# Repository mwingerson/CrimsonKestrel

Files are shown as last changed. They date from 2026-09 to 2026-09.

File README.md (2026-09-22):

### CrimsonKestrel: Open-Source Weather & Solar Edge Node (v1.15.4)
This repository contains the reference architecture for a solar-boosted, low-power environmental monitoring station built around the **ESP32-C6 RISC-V SoC**.

Rather than a fragile "maker-grade" loop sketch, this firmware utilizes a high-reliability **Single-Shot Boot Execution Pattern** paired with robust hardware and software safety nets designed to create an incredibly reliable, "set-it-and-forget-it" testing platform.

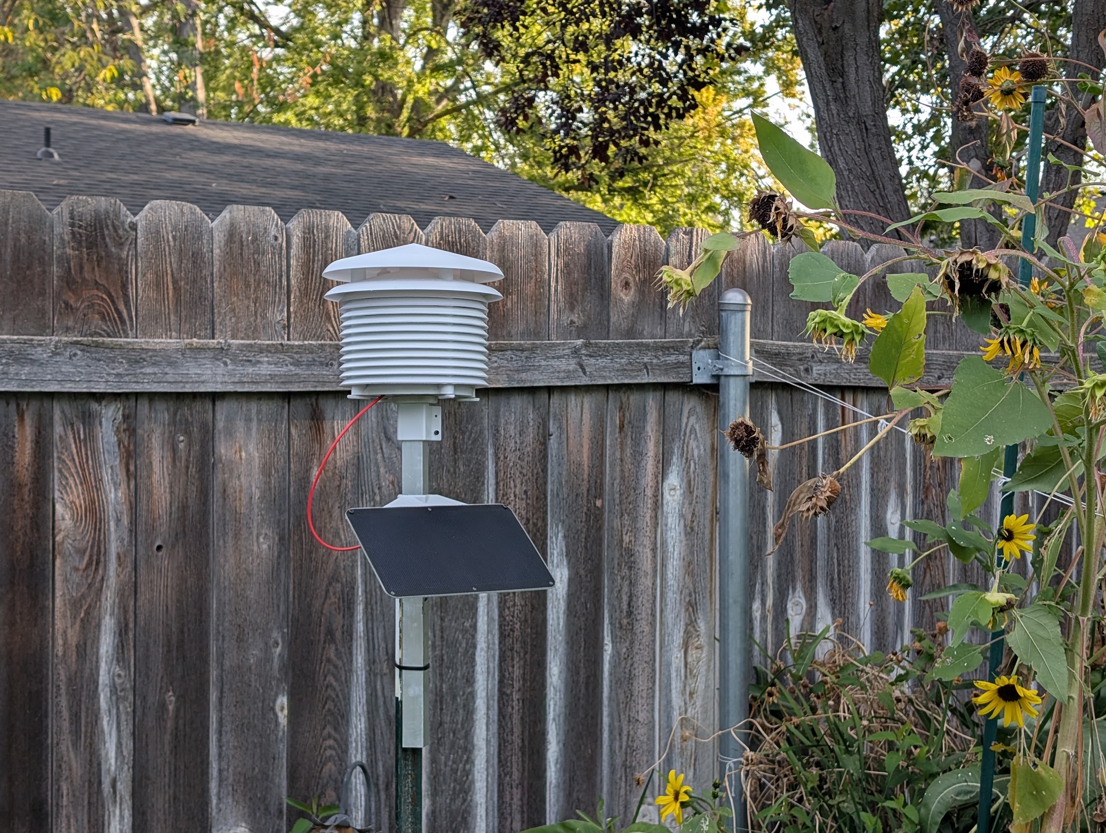
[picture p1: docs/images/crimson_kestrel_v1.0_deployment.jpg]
CrimsonKestrel v1.0 deployed in the backyard


---

#### 📑 Table of Contents
*   [System Architecture: The Hybrid Edge Pattern](#-system-architecture-the-hybrid-edge-pattern)
*   [Repository Directory Tree](#-repository-directory-tree)
*   [Getting Started](#-getting-started)
*   [Standalone Sourcing and Documentation Assets](#-standalone-sourcing-and-documentation-assets)

---

#### 🏗 System Architecture: The Hybrid Edge Pattern
To show quality design decisions while keeping the build highly accessible for makers, the system is architected as an overly robust, modular R&D platform. Instead of a single rigid design, this approach supports a wide range of interchangeable sensors for testing, availability, and budget. This allows anyone from any environment to build a simple, low-cost weather station using parts they already have or can easily afford, while separating physical environmental data collection from heavy data processing:

```
[ Outdoor ESP32-C6 Node ] 
       │ 
       │  (1. Single-Shot Boot: Sample -> Connect -> Decoupled JSON Payloads -> Deep Sleep)
       ▼ 
[ Indoor Gateway (Raspberry Pi @ <GATEWAY_IP>) ]
       │
       ├──► [ MQTT Broker (Mosquitto) ]
       ├──► [ Time-Series Database (InfluxDB) ]
       └──► [ Visualization Dashboard (Grafana) ]
```

*   **The Edge Node:** Wakes up from hardware deep sleep, takes rapid, averaged sensor samples, negotiates Wi-Fi/MQTT sockets, fires decoupled, nested JSON payloads, and drops back into deep sleep.
*   **The Gateway:** Lives indoors on permanent wall power. It handles heavy networking, data storage, third-party weather aggregator API pushing (such as Weather Underground, CWOP, or Home Assistant), and visualization dashboards.

---

#### 📂 Repository Directory Tree
A clean, decoupled directory structure immediately communicates professional maturity:
```
CrimsonKestrel-edge/
├── .gitignore                      <-- Publicly ignores secrets.h
├── LICENSE                         <-- MIT License
├── README.md                       <-- This document
├── BOM.md                          <-- Standalone Bill of Materials & Sourcing Guide
├── BRINGUP.md                      <-- Prototype Assembly & First-Time Bring-Up Guide
├── docs/
│   ├── SETUP.md                    <-- Arduino flashing config & gateway/Docker/Grafana walkthrough
│   ├── REFERENCE.md                <-- Firmware safeguards, LED codes, credentials pattern, JSON schemas
│   ├── images/
│   │   ├── crimson_kestrel_banner.png
│   │   ├── crimson_kestrel_logo.png
│   │   ├── prototype.jpg           <-- Real-world cardboard-mounted prototype photo
│   │   └── crimson_kestrel_v1.0_deployment.jpg <-- v1.0 node deployed in the field
│   ├── adr/
│   │   ├── adr-0001-hybrid-edge.md
│   │   ├── adr-0002-device-observability.md
│   │   ├── adr-0003-decoupled-schemas.md
│   │   └── adr-0004-framework-selection.md
│   └── postmortems/
│       └── mdns-underscore-bug.md  <-- OTA/mDNS underscore bootloop bug write-up
└── firmware/
    └── CrimsonKestrel/
        ├── CrimsonKestrel.ino      <-- Rebranded and updated v1.15.4 Arduino source code
        ├── secrets.h               <-- Private local Wi-Fi and MQTT credentials
        └── secrets.example.h       <-- Public configuration template
└── gateway/
    └── crimson_kestrel_daemon.py   <-- Paho-MQTT gateway subscriber & log rotator
```

---

#### 🚀 Getting Started
*   **Building the hardware:** [BOM.md](BOM.md) (parts/sourcing) and [BRINGUP.md](BRINGUP.md) (assembly and first flash).
*   **Flashing firmware & standing up the gateway stack:** [docs/SETUP.md](docs/SETUP.md).
*   **Firmware safeguards, LED codes, credentials pattern, and JSON telemetry schemas:** [docs/REFERENCE.md](docs/REFERENCE.md).
*   **Design rationale:** [docs/adr/](docs/adr/) — Architectural Decision Records covering the hybrid edge split, device observability, telemetry schemas, and framework selection.
*   **Post-mortems:** [docs/postmortems/mdns-underscore-bug.md](docs/postmortems/mdns-underscore-bug.md) — the mDNS underscore/OTA bootloop bug and its fix.

---

#### 🛠️ Standalone Sourcing and Documentation Assets
To keep the repository clean and avoid support overhead, we maintain detailed, standalone documents for hardware assembly and components:
*   **BOM.md**: Complete, itemized Bill of Materials with pricing, manufacturer part numbers, sourcing links, and direct-solder wiring maps.
*   **BRINGUP.md**: Prototype Assembly & First-Time Flashing Guide detailing physical breadboard layout, star grounding, sensor pull-ups, and step-by-step firmware installation.
*   **docs/SETUP.md**: Arduino IDE flashing configuration and the full gateway/Docker/Grafana setup walkthrough.
*   **docs/REFERENCE.md**: Firmware safeguards, WS2812 LED color codes, the credentials abstraction pattern, and the JSON telemetry schemas.
*   **gateway/crimson_kestrel_daemon.py**: Production-grade Python ingestion daemon that subscribes to raw MQTT streams, validates payload metrics, and commits structured outputs to rolling daily logs.
*   **docs/images/prototype.jpg**: High-resolution photo of our card-mounted rapid prototyping bench used to validate logic states and bus connections during development.
*   **docs/images/crimson_kestrel_v1.0_deployment.jpg**: Photo of the v1.0 node deployed in the field (backyard), shown near the top of this README.
*   **docs/adr/**: Formal Architectural Decision Records (ADRs) documenting core design decisions:
    *   **ADR-0001: The Hybrid Edge Architecture**: Moving heavy processing indoors to achieve a microamp sleep baseline outdoors.
    *   **ADR-0002: Hardware-Based Device Observability**: Opting for register-gated I2C power monitoring over power-bleeding resistive dividers.
    *   **ADR-0003: Decoupled Multi-Topic Telemetry Schemas**: Separating ambient environmental metrics from transient system diagnostics.
    *   **ADR-0004: Development Framework Selection**: Selecting the Arduino ESP32 Core over ESP-IDF or Zephyr RTOS for rapid prototyping and accessibility.
*   **docs/postmortems/**: Write-ups of notable field/integration bugs and their root causes:
    *   **mdns-underscore-bug.md**: The RFC 1035 hostname violation that caused an OTA-triggered crash-on-boot loop.

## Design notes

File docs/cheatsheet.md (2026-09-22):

# 🛠️ Crimson Kestrel: Technical Cheatsheet & Quick Reference

This cheatsheet compiles critical terminal commands, physical pinouts, electrical constraints, and container management instructions into a single rapid-lookup reference guide.

---

## 🔌 1. Hardware Pinout & Wiring Guides

### A. AM2302 / DHT22 Sensor
*   **Protocol:** Proprietary Single-Bus Serial (timing-based signaling, *not* standard 1-Wire).
*   **Logic Level:** Match supply voltage ($V_{CC}$). For $3.3	ext{V}$ microcontrollers (ESP32-C6 / ESP8266), power the sensor with **$3.3	ext{V}$** directly to ensure native $3.3	ext{V}$ logic levels.

#### Standalone 4-Pin Package
Looking directly at the front grid face with pins pointing downwards:
| Pin Number | Name | Connection Target | Purpose |
| :--- | :--- | :--- | :--- |
| **Pin 1 (Left)** | $V_{CC}$ | $3.3	ext{V}$ Bus Rail | Main supply voltage. |
| **Pin 2** | DATA | ESP32-C6 GPIO1 | Single-wire data line. **Requires a physical $4.7	ext{k}\Omega$ to $10	ext{k}\Omega$ pull-up resistor to $V_{CC}$.** |
| **Pin 3** | NC | *Floating* | Not Connected. |
| **Pin 4 (Right)** | GND | GND Bus Rail | Common star ground plane connection. |

*Note: If utilizing a pre-mounted 3-pin breakout module, the pull-up resistor is typically already integrated on the breakout PCB.*

---

### B. Ebyte ESPC6-WROOM-32 Pin Mapping Reference
High-density mapping of active testing pins utilized across the prototype:
| Module Pin | Pin Name | HW Function | Internal Role & Usage |
| :--- | :--- | :--- | :--- |
| **Pin 1** | GND | Ground | Connected to common star ground plane. |
| **Pin 2** | 3V3 | Power In | Rock-solid $3.0	ext{V}$ to $3.6	ext{V}$ supply. |
| **Pin 3** | EN | Chip Enable | Active HIGH (pulls up internally). Pull LOW to turn off. |
| **Pin 15** | IO9 | Boot Strap | **Strapping Pin:** Must be HIGH at reset for normal Flash Boot. Pull LOW at reset to force UART Download Mode. |
| **Pin 17** | IO19 | GPIO19 / SDA | Shared hardware I2C Data line. |
| **Pin 18** | IO20 | GPIO20 / SCL | Shared hardware I2C Clock line. |
| *(see module datasheet)* | IO1 | GPIO1 | DHT22 single-bus serial data input line (chosen to avoid strapping-pin conflicts). |
| **Pin 24** | RXD0 | U0RXD | USB/JTAG Virtual COM port RX (serial console debug). |
| **Pin 25** | TXD0 | U0TXD | USB/JTAG Virtual COM port TX (serial console debug). |

---

## 💻 2. Remote File Transfer & Networking (`scp`)

Always run these commands from your **local terminal** (not from inside an active SSH session):

### A. Push Files / Folders (Local to Gateway)
*   **Recursively Copy Enclosure STL Directory:**
    ```bash
    scp -r ./hardware/enclosure/ <GATEWAY_USER>@<GATEWAY_IP>:~/wrkspc/weather_station_staging/hardware/
    ```
*   **Push Single Configuration File:**
    ```bash
    scp ./docker-compose.yml <GATEWAY_USER>@<GATEWAY_IP>:~/wrkspc/weather_station_staging/
    ```

### B. Pull Files / Folders (Gateway to Local)
*   **Download Completed Telemetry CSV Logs:**
    ```bash
    scp -r <GATEWAY_USER>@<GATEWAY_IP>:~/wrkspc/weather_station_staging/data/ ~/Downloads/
    ```
*   **Pull Single Gateway Daemon Script:**
    ```bash
    scp <GATEWAY_USER>@<GATEWAY_IP>:~/wrkspc/weather_station_staging/gateway/crimson_kestrel_daemon.py ~/Downloads/
    ```

### C. SSH Command-Line Escape Sequence (Transfer on the Fly)
If you are already in an active SSH session and want to issue an inline recursive transfer back to your local computer without opening a new tab:
1. Hit `Enter`.
2. Type **`~C`** (Tilde followed by capital C). The prompt will change to `ssh>`.
3. Issue the local execution escape:
   ```text
   ssh> ! scp -r <GATEWAY_USER>@<GATEWAY_IP>:/home/<GATEWAY_USER>/wrkspc/weather_station_staging/ ~/Downloads/
   ```
4. Hit `Enter` to return seamlessly to your active remote shell.

---

## 🤖 3. Docker & Stack Observability Reference

### A. Quick Diagnostics & Status
*   **List Running Containers & Exposed Ports:**
    ```bash
    docker ps
    ```
*   **Show All Containers (Including Stopped/Crashed Services):**
    ```bash
    docker ps -a
    ```
*   **Tail Live Processing Logs (Last 50 Lines):**
    ```bash
    docker logs crimson_daemon --tail 50
    docker logs crimson_mosquitto --tail 50
    docker logs crimson_influxdb --tail 50
    ```

### B. Host & Stack Permission Maintenance
*   **Resolve Docker API "Permission Denied" Errors (Add User to Group):**
    ```bash
    sudo usermod -aG docker $USER
    newgrp docker
    ```
*   **Resolve Grafana "Permission Denied" Directory Write Loops:**
    ```bash
    sudo chown -R 472:472 ./grafana/data
    ```

### C. Resetting and Wiping Stack Cache (The Data Wipe Options)
*   **Nuclear Option: Purge Entire Host Docker Cash (All Containers, Volumes, & Networks):**
    ```bash
    docker system prune -a --volumes -f
    ```
*   **Reset Weather Station Stack Only (Clear Persistent Data Volumes):**
    ```bash
    docker compose down -v
    docker compose up -d
    ```

---

## 📡 4. MQTT Broker & Ingestion Diagnostics

### A. Monitoring Live Subnet Traffic (MQTT Sniffing)
*   **Listen to All Subscribed Topics (Great for confirming packet ingress):**
    ```bash
    docker exec -it crimson_mosquitto mosquitto_sub -h localhost -p 1883 -t "#" -v
    ```
*   **Subscribe Specifically to Aligned Environmental Topics:**
    ```bash
    docker exec -it crimson_mosquitto mosquitto_sub -h localhost -p 1883 -t "telemetry/+/weather" -v
    ```

### B. Simulating Telemetry Ingress (Manual Publishing)
*   **Post Environmental Payload to Broker:**
    ```bash
    docker exec -it crimson_mosquitto mosquitto_pub -h localhost -p 1883 -t "telemetry/weather_node_01/weather" -m '{"client_id":"weather_node_01","environment":{"temperature_c":22.3,"humidity_pct":38.5}}'
    ```
*   **Post Power & Diagnostics Payload to Broker:**
    ```bash
    docker exec -it crimson_mosquitto mosquitto_pub -h localhost -p 1883 -t "telemetry/weather_node_01/system" -m '{"client_id":"weather_node_01","system":{"version":"1.15.4","uptime_ms":3585},"power":{"bus_voltage_v":3.82,"load_current_ma":36.9,"shunt_voltage_mv":3.69}}'
    ```

---

## 📦 5. Firmware Build & Erase Tools (CLI Flash Option)

If pushing firmware directly over USB or utilizing emergency recovery CLI tools rather than the Arduino IDE:

### A. Arduino CLI Library Ingress
*   **Install Required Library Dependencies:**
    ```bash
    arduino-cli lib install "PubSubClient"
    ```

### B. Direct Python-Based Over-The-Air (OTA) Flash
If local mDNS network resolution fails in the Arduino IDE port selector list, push the compiled application binary directly via IP:
```bash
python3 ~/.arduino15/packages/esp32/hardware/esp32/3.0.0/tools/espota.py -i <NODE_IP> -p 8266 -a <OTA_PASSWORD> -f /tmp/arduino/build/CrimsonKestrel.ino.bin
```

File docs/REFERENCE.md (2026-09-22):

# Reference: Firmware Safeguards, LED Codes, Credentials Pattern & Telemetry Schemas

Lookup material for the firmware's internals — safety nets, status LED meanings, the credentials
pattern, and the JSON payloads it publishes. For flashing/gateway setup steps, see
[SETUP.md](SETUP.md).

---

#### 🛡 Core Firmware Safeguards (The "Bulletproofing")
Let's be honest: nobody wants to drag a 20-foot ladder out to their roof in the middle of a freezing downpour just to press a tiny physical reset button because the Wi-Fi hiccuped or an I2C sensor locked up. To prevent those unnecessary roof-climbing adventures and keep your station running 24/7, the firmware includes several robust, built-in safety nets:

##### 1. Hardware Watchdog Timer (WDT)
If an I2C transaction hangs due to electrical noise, or a Wi-Fi handshake locks up, the hardware watchdog automatically triggers a full system reset.
*   **Implementation:** The ESP32-C6's internal Main System Watchdog Timer (MWDT) is initialized at boot with a **15-second timeout**. The watchdog is fed continuously through the execution path; if any task hangs, the hardware reboots the processor to recover.

##### 2. Connection-Timeout & Graceful Fallbacks
A major failure mode in field deployments is a node getting stuck trying to connect to an offline router, draining its battery in minutes.
*   **Implementation:** The Wi-Fi connection loop uses a non-blocking timeout. If connection is not established within **10 seconds**, the code gracefully halts, aborts transmission, configures low-power states, and goes to sleep.

##### 3. Data Sanitization & Range Validation
Physical sensors can report NaN (Not a Number) or severe spikes during startup transients or low-voltage states.
*   **Implementation:** Outlier range validation is run on all telemetry before packaging:
    *   **DHT22:** Rejects relative humidity readings outside 0.0 to 100.0 and NaN states.
    *   **INA219:** Rejects bus voltage readings outside 0.0 V to 26.0 V (max chip limit) or NaN states.
    *   If a reading is invalid, the node logs the error, flags the payload as invalid, and bypasses transmission to protect database hygiene.

##### 4. Cloud-Driven Debug Sleep Override State
During active workspace debugging, waiting 5 minutes between iterations slows down development. The node supports dynamic state shifting:
*   On boot, the node subscribes to a command topic. If it reads a retained "ON" debug command, it overwrites its standard 5-minute deep sleep timer with a rapid **5-second cycle** and pulses its RGB LED to signal active debug mode. This allows you to observe full boot-up sequences, Wi-Fi negotiations, and sleep routines rapidly at your desk.

---

#### 🚦 Diagnostic Device Observability (WS2812 LED)
##### 🎨 WS2812 Visual Status LED Color Codes
To assist in local debugging and bring-up without having a serial monitor attached, the onboard WS2812 LED flashes standard, high-density color-coded states. Because these color codes are documented directly using GitHub-compatible hex swatches, they will render as beautifully colored visual dots directly on your GitHub landing page:

| LED State | Visual Swatch | Hex Code | R, G, B | System State & Meaning |
| --- | --- | --- | --- | --- |
| **Solid Orange** | 🟧 #964B00 | #964B00 | 150, 75, 0 | **System Booting:** Microcontroller powering up, establishing internal clock registers, and configuring hardware peripherals. |
| **Pulsing Yellow** | 🟨 #964B00 | #964B00 | 150, 75, 0 (pulse) | **Wi-Fi Negotiating:** Active, non-blocking connection attempt to your local Wi-Fi gateway router. |
| **Flash Green** | 🟩 #009600 | #009600 | 0, 150, 0 | **Publish Successful:** Environmental and system power telemetry successfully packaged and published to your MQTT broker. |
| **Solid Purple** | 🟪 #640064 | #640064 | 100, 0, 100 | **Maintenance Window:** Active 2-second idle window listening on command topics for OTA override packages. |
| **Pulsing Cyan** | ⬜ #009696 | #009696 | Variable | **Debug Loop Active:** Dynamic MQTT debug mode triggered; deep sleep is overridden to a rapid 5-second sampling loop. |
| **Solid Blue** | 🟦 #000096 | #000096 | 0, 0, 150 | **OTA Mode Engaged:** Maintenance Mode active; the web-server is open and awaiting wireless firmware binaries. |
| **Pulsing Blue** | 🟦 #000096 | #000096 | 0, 0, pulse | **Active OTA Download:** High-speed wireless download of new compiled .bin firmware packets. |
| **Solid Cyan** | ⬜ #009696 | #009696 | 0, 150, 150 | **Flash Write:** Actively committing new firmware blocks to local partition slots. |
| **Solid Green** | 🟩 #00FF00 | #00FF00 | 0, 255, 0 | **Flash Success:** Firmware update completely written and verified; system is rebooting into the new software layer. |
| **Solid Red** | 🟥 #960000 | #960000 | 150, 0, 0 | **System Error:** Hardware initialization failure (DHT22 missing, INA219 offline), or data sanitization outlier rejected. |
| **Fast Red Flash** | 🟥 #960000 | #960000 | 150, 0, 0 (fast) | **Network Timeout:** Wi-Fi connection timed out or MQTT broker unreachable. Pipeline gracefully aborted to protect battery. |

---

#### 🔒 Safe Credentials Abstraction Pattern
To keep your private home router credentials and server IP addresses completely safe from leakages on public repositories, **CrimsonKestrel** uses a professional **Safe Include Pattern**.
Inside the main firmware sketch, the C++ preprocessor dynamically checks for the presence of a local, untracked secrets.h file:

```cpp
#if __has_include("secrets.h")
  #include "secrets.h"         // Pulls actual credentials locally
#else
  #include "secrets.example.h" // Fallback template so repo compiles out-of-the-box
#endif
```

By adding `secrets.h` and `*secrets.h` to your `.gitignore` file, your private information remains strictly on your local PC (`DIBShip`) while others can easily clone the repo and compile it using the provided `secrets.example.h` blueprint!

---

#### 📊 Decoupled JSON Telemetry Schemas (v1.15.4)
To maintain a clean database structure and separate transient environmental states from system diagnostics, the node publishes two distinct JSON payloads during its single-shot boot routine:

##### 1. Ambient Weather Telemetry
Pushed directly to your database parser to record ambient environmental updates:
**Topic:** `telemetry/weather_node_01/weather`
```json
{
  "client_id": "weather_node_01",
  "environment": {
    "temperature_c": 19.6,
    "humidity_pct": 38.7
  }
}
```

##### 2. Device System & Power Observability
Pushed to your system health logger to track battery charge levels and hardware status:
**Topic:** `telemetry/weather_node_01/system`
```json
{
  "client_id": "weather_node_01",
  "system": {
    "version": "1.15.3",
    "uptime_ms": 3594
  },
  "power": {
    "bus_voltage_v": 3.93,
    "load_current_ma": 30.4,
    "shunt_voltage_mv": 3.04
  }
}
```

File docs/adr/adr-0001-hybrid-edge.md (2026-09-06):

# ADR-0001: Hybrid Edge Architecture

## Status
Approved

## Context
To build a reliable solar-powered weather station, we evaluated two primary architectural patterns for the core processing system:

1. **Outdoor Single-Board Computer (SBC):** Deploying a Linux-based SBC (such as a Raspberry Pi) directly in the outdoor weather station enclosure [cite: 427]. This offers extreme ease of development, high-level programming language support (Python pipelines), and native database/broker execution at the physical edge [cite: 428].
2. **Hybrid Edge Architecture:** Splitting processing and environmental sampling between an ultra-low-power outdoor microcontroller (MCU) edge node and a permanently powered indoor Linux gateway [cite: 429, 436].

### Power & Cost Engineering Analysis
A standard Linux-based SBC (e.g., Raspberry Pi 4) lacks a native hardware-level deep sleep state and draws a continuous active load of roughly 3 Watts (~600mA @ 5V) [cite: 428, 430]. Under extreme off-grid conditions (designing for 4 days of solar blackout/autonomy at mid-latitudes), the energy requirements scale exponentially [cite: 431]:

* **Daily Energy Draw:** 3W * 24h = 72 Watt-hours (Wh) per day [cite: 430].
* **4-Day Autonomy Target:** 72 Wh/day * 4 days = 288 Wh [cite: 431].
* **Battery Sizing (12V nominal LiFePO4):** 288 Wh / 12V = 24 Amp-hours (Ah) [cite: 431].
* **Solar Panel Sizing (4 winter peak sun hours):** 100 Wh target / 4 hours = 25 Watts minimum [cite: 432]. Applying a standard 1.5x to 2x safety factor requires a **50W to 100W monocrystalline solar panel** [cite: 432].

This outdoor SBC approach demands a heavy, expensive system [cite: 431, 435]: a motorcycle-sized 12V LiFePO4 battery [cite: 431], a massive solar panel [cite: 432], a commercial MPPT charge controller [cite: 433], an industrial DC-DC buck converter [cite: 433], and a dedicated low-power hardware supervisor to trigger clean shutdowns to prevent SD card corruption [cite: 433]. This heavily violates our core constraint of building an accessible, highly replicable, and low-cost R&D station [cite: 413, 435].

Conversely, an optimized microcontroller edge node can utilize a **Single-Shot Boot Execution Pattern** [cite: 235, 413]: waking up from hardware deep sleep, taking rapid averaged sensor samples, negotiating Wi-Fi/MQTT sockets, transmitting a lightweight telemetry packet, and immediately returning to deep sleep [cite: 235]. An MCU like the ESP32-C6 has a deep-sleep current draw of approximately 15–30 µA [cite: 235], allowing the entire outdoor setup to run continuously on a single 18650 Lithium-Ion cell and a compact, lightweight 5V solar panel [cite: 235, 435].

## Decision
We reject the outdoor Single-Board Computer design and officially adopt the **Hybrid Edge Architecture** [cite: 429, 436]:

1. **Outdoor Edge Node:** Standardize on an ultra-low-power ESP32-C6 microcontroller node running a non-blocking single-shot boot pattern [cite: 235, 413]. It is powered by a small 5V solar panel and a single 18650 battery cell [cite: 235, 435].
2. **Indoor Gateway:** Deploy a Linux-based gateway (such as a Raspberry Pi) **indoors on permanent wall power** [cite: 429, 436]. This gateway hosts the local MQTT broker (Mosquitto), a time-series database (InfluxDB), and a visualization platform (Grafana) [cite: 429, 436]. The gateway is responsible for subscribing to the node's telemetry, handling data storage, running calibration algorithms, and pushing data to third-party aggregators (such as Weather Underground, CWOP, or Home Assistant) [cite: 423, 429].

## Consequences

### Consequences (Pros)
* **Drastic SWaP-C Reduction:** Eliminates the need for bulky 12V marine/motorcycle batteries [cite: 431] and large 50W+ solar panels [cite: 432]. The system can be safely assembled and deployed on a standard 3D-printed mounting arm using affordable, widely available maker hardware [cite: 235, 435].
* **System Durability:** Minimizes outdoor failure points. Eliminates mechanical wear, moving parts, and complex off-grid power-switching regulators in the weather enclosure [cite: 433, 477].
* **No SD Card Corruption Risk:** The outdoor node operates completely stateless out of raw flash memory, while the database runs on a safe, indoor, line-powered system [cite: 429, 433].
* **Clean Separation of Concerns:** The outdoor node remains purely an environmental telemetry transducer [cite: 235], while the gateway handles heavy networking, processing, and visualization tasks [cite: 429].

### Consequences (Cons)
* **Local Subnet Requirement:** The outdoor node must remain within wireless range of the indoor gateway's local network (Wi-Fi 6 or mDNS range) [cite: 27, 429].
* **Gateway Dependency:** Environmental data cannot be visualized or aggregated if the indoor gateway is powered off or disconnected from the local network.

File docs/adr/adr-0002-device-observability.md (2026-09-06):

# ADR-0002: Hardware-Based Device Observability

## Status
Accepted

## Context
Deploying an outdoor, solar-boosted telemetry node requires real-time monitoring of battery state-of-charge (SoC) and system current draw to predict run-time limits and detect hardware anomalies. 

We evaluated two primary power-sensing methods:
1. **Resistive Voltage Divider (Analog ADC Pin):** A standard two-resistor network stepping down battery voltage to fit within the microcontroller's ADC limits.
2. **Dedicated I2C Power Monitor (INA219 / INA226):** An external integrated circuit measuring both bus voltage and differential voltage drop across a low-resistance inline shunt.

### Trade-Off Analysis

| Criteria | Resistive Voltage Divider (ADC) | Dedicated I2C Power Monitor (INA219) |
| :--- | :--- | :--- |
| **Metrics Captured** | Voltage only (non-linear battery estimation) | Voltage, Shunt Voltage, Current (mA), and calculated Power (mW) |
| **Parasitic Current** | Constant leakage to ground (mitigated only via complex high-side MOSFET gating) | Native, register-driven software shutdown modes reducing current draw to < 15 µA |
| **Noise Immunity** | Highly susceptible to RF transients during active Wi-Fi transmission bursts | Isolated digital I2C telemetry with internal averaging and high-frequency filtering |
| **Component Count** | 2 resistors, 1 P-channel MOSFET, 1 NPN transistor, biasing passives | 1 integrated circuit breakout, decoupling capacitor |
| **PCB Footprint** | Large discrete footprint, complex trace routing | Small, modular footprint sharing the existing digital I2C bus |

## Decision
We decided to standardize on the **INA219 high-side I2C current and power monitor** for hardware-based device observability. 

The sensor will be placed upstream of the main voltage regulation and distribution rails (high-side sensing) to ensure an unbroken ground plane across the microcontroller and other peripherals, preventing ground loop offsets.

## Consequences
* **Precision Telemetry:** We gain real-time, microamp-resolution insights into the active transmission spikes and deep-sleep baselines of the microcontroller.
* **Firmware Complexity:** We must initialize and configure the INA219 via standard I2C wire transactions at boot.
* **Zero Parasitic Bleed:** Prior to triggering the microcontroller's deep sleep state, the firmware must write to the INA219 Configuration Register to put the IC into I2C power-down mode (~15 µA draw).
* **Shared Bus Architecture:** The INA219 shares physical I2C pins with any future expansion sensors, eliminating GPIO pin-budget bottlenecks.

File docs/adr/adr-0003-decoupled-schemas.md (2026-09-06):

# ADR-0003: Decoupled Multi-Topic Telemetry Schemas

## Status
Accepted

## Context
In early prototyping phases, environmental weather stations typically bundle all sensor outputs (temperature, humidity, battery voltage, up-time, etc.) into a single, monolithic JSON payload published to a single MQTT topic.

While simple to write, this monolithic approach presents severe architectural drawbacks for production-scale deployments:
* **Database Hygiene:** Systems tracking ambient environmental metrics (e.g., InfluxDB) are forced to continuously ingest and store static system metadata (such as firmware version and boot up-time).
* **Payload Bloat:** Network bandwidth is wasted sending slow-changing system diagnostics at the same frequency as rapid environmental changes.
* **Automation Coupling:** Home automation systems (like Home Assistant) must run complex parsing scripts on a single payload to extract independent entities.

## Decision
We decided to **decouple the telemetry payloads** into two distinct, structured JSON schemas published to independent MQTT topics:

1. **Environmental Weather Telemetry (`telemetry/<CLIENT_ID>/weather`):**
   Contains strictly ambient environmental metrics.
   ```json
   {
     "client_id": "<CLIENT_ID>",
     "environment": {
       "temperature_c": 19.6,
       "humidity_pct": 38.7
     }
   }
   ```

2. **System & Power Observability (`telemetry/<CLIENT_ID>/system`):**
   Contains system metadata, diagnostic metrics, and battery health telemetry.
   ```json
   {
     "client_id": "<CLIENT_ID>",
     "system": {
       "version": "1.15.2",
       "uptime_ms": 3594
     },
     "power": {
       "bus_voltage_v": 3.93,
       "load_current_ma": 30.4,
       "shunt_voltage_mv": 3.04
     }
   }
   ```

## Consequences
* **Decoupled Data Ingestion:** Database parsers and time-series databases can subscribe strictly to the `/weather` topic, preserving database hygiene.
* **Payload Efficiency:** System diagnostic payloads can eventually be duty-cycled at a lower rate than environmental payloads to conserve battery power.
* **Cleaner Home Automation:** Home Assistant can consume the two topics independently, mapping entities directly to their logical controls and graphs without heavy JSON post-processing.

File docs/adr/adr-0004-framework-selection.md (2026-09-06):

# ADR-0004: Development Framework Selection

## Status
Accepted

## Context
We evaluated the optimal software platform and development framework for writing high-reliability, low-power edge firmware on the ESP32-C6 RISC-V microcontroller.

Three primary options were considered:
1. **Espressif IoT Development Framework (ESP-IDF):** The native, bare-metal C-based SDK provided by Espressif.
2. **Zephyr RTOS:** A modular, secure, open-source real-time operating system optimized for resource-constrained resource devices.
3. **Arduino ESP32 Core (v3.0.0+):** A highly accessible C++ framework built on top of FreeRTOS tasks and the underlying ESP-IDF port.

### Trade-Off Analysis

| Criteria | Native ESP-IDF | Zephyr RTOS | Arduino ESP32 Core |
| :--- | :--- | :--- | :--- |
| **Low-Power Control** | Absolute, registers-level deep-sleep configurations | Excellent, native power-management subsystem | Fully accessible (wraps native ESP-IDF system APIs) |
| **Development Velocity** | Slow (verbose APIs, steep learning curve) | Slow (complex device-tree configurations, tooling setup) | **Extremely Fast** (large library ecosystem, clean syntax) |
| **Portability** | Locked to Espressif silicon | Excellent cross-architecture abstraction | Portable across major Maker/Hobbyist hardware |
| **Library Availability** | Moderate (requires porting custom drivers) | Low (requires custom Zephyr-compliant device-tree drivers) | **Excellent** (thousands of community-maintained drivers) |
| **Watchdog & OTA** | Robust, requires custom partition logic | Native, robust | **Native & Simplified** (uses mDNS, ArduinoOTA, and WDT libraries) |

## Decision
We decided to standardize on the **Arduino ESP32 Core (v3.0.0+)** running on top of underlying **FreeRTOS** APIs.

While Zephyr RTOS and native ESP-IDF are outstanding for enterprise-only products, the Arduino ESP32 Core offers the perfect balance of development velocity and hardware accessibility for a robust, open-source research and development platform. It allows us to utilize the extensive Arduino library ecosystem for sensor bring-up while still leaving low-level ESP-IDF system APIs (like deep-sleep and watchdog timers) fully accessible.

## Consequences
* **Rapid Prototyping:** We can easily swap out complex sensors (such as moving from a basic DHT22 to a Sensirion SPS30 or AS3935 lightning sensor) using verified, pre-existing libraries.
* **Production-Grade Safety:** We still maintain enterprise-level safety nets (including the 15-second Main System Watchdog and OTA rollback partitions) by calling direct low-level ESP-IDF functions when required.
* **Accessibility:** Other developers can easily clone, audit, and compile the firmware in their local environments without needing to configure complex command-line toolchains or device-trees.

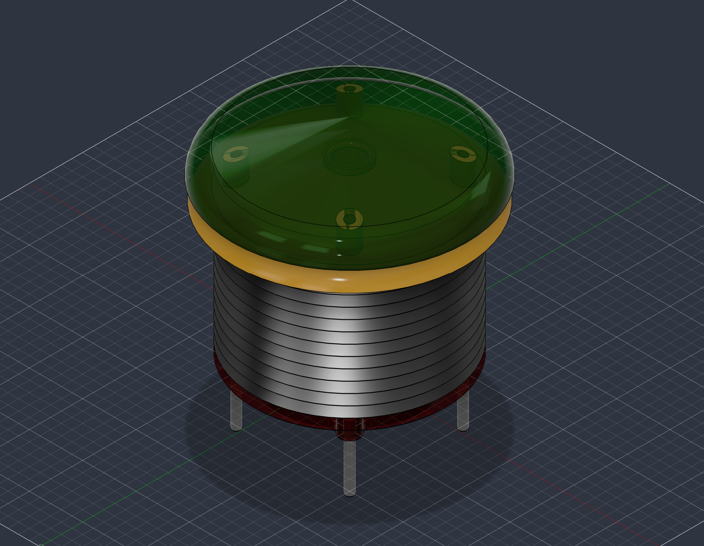
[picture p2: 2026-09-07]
docs/images/enclosure_3D_model_v0.5.png

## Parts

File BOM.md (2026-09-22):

# Bill of Materials (BOM) — CrimsonKestrel

This document serves as the official, production-grade Bill of Materials (BOM) and Sourcing Guide for **CrimsonKestrel**, a highly optimized, solar-powered edge telemetry node built around the ESP32-C6 RISC-V SoC. 

This reference architecture serves as an overly robust, low-power R&D platform designed to be highly accessible and affordable for hobbyists. By utilizing a single 18650 Lithium-Ion cell, a small solar panel, and modular breakout boards, anyone can build a reliable 24/7 weather station using the parts they have available or can afford, while maintaining an ultra-low sleep current baseline (~15–30 µA).

---

## 📊 Phase 1: MVP Core Bill of Materials

These components form the baseline telemetry node designed in Phase 1. All connections are designed for standard **2.54mm (0.1") pitch male/female headers** or direct-solder prototyping boards.

| Ref | Component Name | Manufacturer / MPN | Key Technical Specifications | Qty | Est. Cost (USD) | Primary Sourcing | Design & Integration Notes |
| :--- | :--- | :--- | :--- | :--- | :--- | :--- | :--- |
| **U1** | **ESP32-C6 Dev Board** | Meshnology / [QS-ESP32 C6 N16](https://www.amazon.com/dp/B0FKH69BP7) | Core board with 16MB Flash, RISC-V Single-Core CPU, 2.4GHz Wi-Fi 6, BLE 5, Zigbee 3.0, and Thread. Compatible with ESP32-WROOM series boards, Type-C connector. | 1 | $4.50 – $6.00 | [Amazon](https://www.amazon.com/dp/B0FKH69BP7) | Provides the core processing, network socket negotiation, and deep sleep routines. Features USB CDC for direct debug monitoring over Type-C. |
| **U2** | **INA219 Power Monitor Breakout** | Texas Instruments / INA219AIDR (Adafruit PID 904 or Generic) | I2C high-side current and voltage monitor, ±26V common-mode input range, 12-bit ADC, onboard 0.1Ω 1% shunt resistor. | 1 | $2.00 – $4.50 | Mouser, Adafruit, Amazon | Monitors battery health and real-time current draw. Breakout includes physical 10kΩ pull-up resistors on SDA/SCL lines. |
| **SEN1** | **DHT22 Humidity & Temp Sensor** | Aosong / AM2302 | Ambient temperature range: -40°C to 80°C (±0.5°C), relative humidity: 0–100% (±2–5% RH). Single-bus serial protocol. | 1 | $3.00 – $4.00 | Adafruit, SparkFun, Amazon | Measures primary environmental metrics. Can use standard 3-pin PCB module with pre-installed pull-up, or bare 4-pin sensor with external resistor. |
| **D1** | **WS2812 RGB LED** | Worldsemi / WS2812B (Onboard GPIO8) | Addressable RGB LED, single-wire control protocol. Integrated directly on Dev Board. | 1 | Included | Built-in on Node Board | Configured in firmware as a multi-state visual indicator for booting, network socket errors, active debug mode, and OTA progress. |
| **BAT1** | **18650 Li-Ion Cell** | Samsung / INR18650-30Q or Panasonic / NCR18650B | 3.7V Nominal, 3000mAh capacity, chemistry optimized for high reliability and steady discharge. | 1 | $5.00 – $7.00 | 18650BatteryStore, LiionWholesale | Main system power reservoir. Size is highly optimized for multi-week operation even under extended solar blackout. |
| **U3** | **Solar Charger & Board** | WatangTech / [5V Solar Charge Controller](https://www.amazon.com/dp/B0FQP915R9) | JEITA Li-ion Battery Charger with dual USB output, 5V and 3.3V power rails, and built-in 18650 battery holder. Compatible with Arduino, RPi, STM32. | 1 | $5.00 – $7.00 | [Amazon](https://www.amazon.com/dp/B0FQP915R9) | Automatically manages solar charging cycles for the 18650 cell, and exposes highly convenient 5V and 3.3V supply lines. |
| **PV1** | **Monocrystalline Solar Panel** | Voltaic Systems / [5.5 Watt 6 Volt Panel](https://www.amazon.com/dp/B085W9KG6V) | 5.5 Watt, 6 Volt high-performance monocrystalline cells. Waterproof, UV-resistant, scratch-resistant ETFE laminate casing. | 1 | $35.00 – $40.00 | [Amazon](https://www.amazon.com/dp/B085W9KG6V) | High-durability charging source designed to gather generous power even under partial shade or low daylight winter months. |
| **R1** | **DHT22 Pull-Up Resistor** | Generic / Metal Film 1/4W | 4.7kΩ to 10kΩ resistor, 1% tolerance. | 1 | $0.10 | Mouser, DigiKey, Parts Bin | Placed between VCC and DATA pins of bare 4-pin DHT22 to keep single-bus line from floating. Skip if using 3-pin breakout board. |

---

### 🚦 The WS2812 "Device Observability" Pivot
A common question when designing low-power remote nodes is: *Why spend precious power on an addressable WS2812 RGB LED (which can draw up to 50mA when fully bright) instead of a simple single-color indicator LED or no LED at all?*

The decision is driven by **strict engineering trade-offs** and **field survivability**:
1. **Single-Pin Multi-State Diagnostics:** A traditional single-color status LED only offers two states (On or Off). To represent the multiple critical stages of our single-shot boot pipeline (Booting -> Sensor Init -> Wi-Fi Connect -> MQTT Handshake -> Payload Validation -> Active Listening -> Sleep), we would need a bank of 5+ separate LEDs, which would hijack precious GPIO pins, increase BOM costs, and clutter the physical board. The WS2812 uses **exactly one physical GPIO pin (GPIO8)** to output a high-density, multi-color diagnostic spectrum.
2. **Zero-Power Deep Sleep Isolation:** The WS2812 is only powered and active during the brief **2-to-3 second active boot and transmission window**. The instant the transmission completes and the node prepares to sleep, the firmware executes `statusLED.clear()` and disables the LED completely. During deep sleep, the LED's power draw is non-existent, making its net daily energy consumption negligible (under 0.05% of our daily battery capacity).
3. **The "No-Ladder" Diagnostics Rule:** Let's be honest: nobody wants to drag a 20-foot ladder out to their roof in a freezing downpour just to attach a physical USB serial debugging cable because the station stopped updating. Having a high-density RGB status indicator allows you to perform a simple "ground-level binocular test" or check it from a window. If the node is struggling with your router, it pulses yellow; if the sensor is disconnected, it glows solid red; if it is ready for a firmware update, it turns solid blue.

## 🔌 Core Solder-Direct Master Wiring Map (PTH Spacing)

By designing for direct pin-to-pin soldering using standard **2.54mm (0.1") pitch pin headers**, we eliminate expensive proprietary connectors, lowering BOM costs and simplifying assembly.

All breakout modules share the physical I2C bus lines in parallel:

| Breakout Board Pin | ESP32-C6 Pin | Function | Electrical / Configuration Notes |
| :--- | :--- | :--- | :--- |
| **VCC / VIN (All)** | **3.3V** | Power Rail | Main system power (Common 3.3V supply). |
| **GND (All)** | **GND** | Ground Plane | Star ground configuration to prevent loops and signal noise. |
| **SDA (INA219)** | **GPIO19** | I2C Data | Communicates battery diagnostics. Shared hardware I2C bus. |
| **SCL (INA219)** | **GPIO20** | I2C Clock | Shared hardware I2C bus lines. |
| **DATA (DHT22)** | **GPIO1** | Single-Bus Serial | Uses an internal or external 10kΩ pull-up resistor to 3.3V. Chosen to avoid ESP32-C6 strapping-pin conflicts. |

---

## 💡 Sourcing & Assembly Best Practices

To ensure "right-first-time" assembly and protect against field failures, follow these professional prototyping rules:

### 1. The I2C Pull-Up "BOM Hack"
Standard I2C buses require physical pull-up resistors (typically $2\text{k}\Omega$ to $5\text{k}\Omega$) on SCL and SDA to ensure reliable high-speed communication. Relying strictly on the ESP32-C6's internal weak software pull-ups (typically $45\text{k}\Omega$) causes signal degradation and eventual system hangs.
*   **The Hack:** Standard off-the-shelf INA219 breakout modules already feature physical $10\text{k}\Omega$ pull-up resistors pre-soldered on-board. Wiring the breakout module directly to the I2C lines provides the necessary physical pull-up network for the entire bus, eliminating the need to solder discrete resistors on your proto-board.

### 2. Ground Plane Integrity & Star Grounding
High-speed wireless transmissions (ESP32-C6 Wi-Fi 6 active bursts up to 350mA) introduce significant electrical noise into physical power rails.
*   **Best Practice:** Implement a strict **Star Ground Configuration** where the ground pins from the ESP32-C6, INA219, and DHT22 are soldered to a single physical point on your perfboard. This prevents ground loops and stabilizes readings.
*   **Decoupling:** Place a $0.1\mu\text{F}$ ceramic capacitor close to the power pins of each peripheral to filter high-frequency switching noise.

---

## 🛣️ Phase 2: Extensible Platform Sourcing Guide

Because your battery capacity is large (3000mAh) and the ESP32-C6's single-shot sleep routine draws minimal power, you have abundant energy reserves. This allows you to scale up the weather station dynamically in Phase 2 by plugging these professional modules straight into your physical I2C bus and GPIO lines:

### 1. Wind Speed: Hobbyist Cup Anemometer
*   **Estimated Cost:** ~$15.00 – $25.00 (Standard replacement cup assemblies).
*   **Interface:** Digital GPIO Pin (Magnetic reed switch output).
*   **Integration:** Connect to **GPIO3**. Configured in firmware using the ESP32-C6's hardware **Pulse Count Controller (PCNT)** peripheral to count wind speed pulses in the background without stealing CPU cycles.

### 2. Storm Tracking: AS3935 Franklin Lightning Sensor
*   **Estimated Cost:** ~$22.00 – $35.00 (DFRobot Gravity or SparkFun Qwiic breakouts).
*   **Interface:** I2C (shares GPIO19/SDA and GPIO20/SCL) + 1 Hardware Interrupt Pin.
*   **Integration:** Connect the interrupt line to **GPIO2**. It will automatically wake the ESP32-C6 from deep sleep when electromagnetic storm pulses are detected up to 40 km away.

### 3. Air Quality: Sensirion SPS30 Particulate Matter Sensor
*   **Estimated Cost:** ~$35.00 – $45.00.
*   **Interface:** I2C (shares GPIO19/SDA and GPIO20/SCL).
*   **Integration:** Features an automated high-RPM self-cleaning fan routine to prevent long-term optical drift. Requires a gated load switch (such as a P-channel MOSFET) to completely isolate and power-down the sensor's fan during deep-sleep states. ⚠️ **Pin conflict:** GPIO1 is already used for the DHT22 data line (see wiring table above) — pick a different free GPIO for this switch when implementing Phase 2.

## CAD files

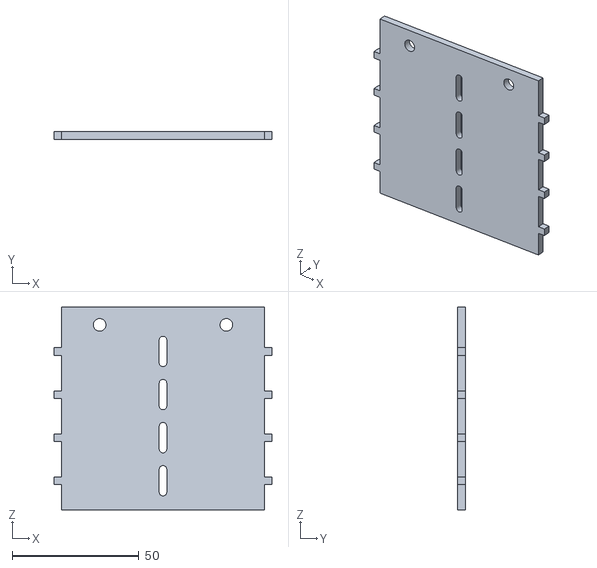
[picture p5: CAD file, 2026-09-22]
hardware/enclosure/electronics_plate.stl
86.0 x 3.00 x 80.0

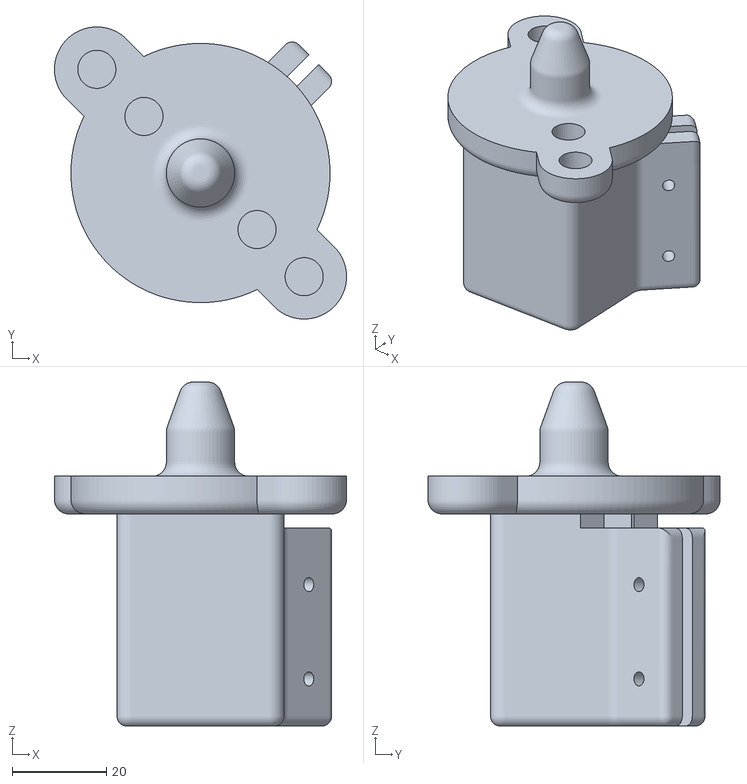
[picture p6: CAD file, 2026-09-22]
hardware/enclosure/mount_square_tubing.stl
62.0 x 62.0 x 73.0

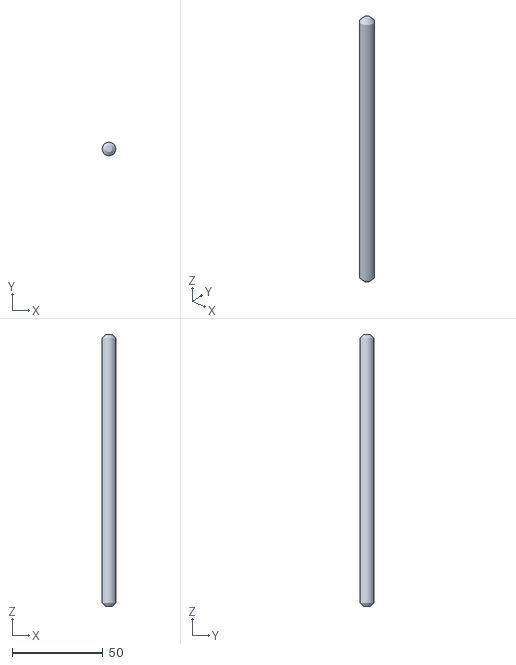
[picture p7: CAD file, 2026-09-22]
hardware/enclosure/vertical_rod_test.stl
7.50 x 7.50 x 150.0

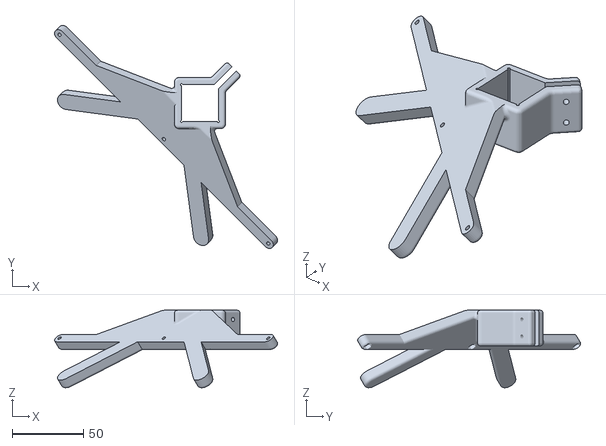
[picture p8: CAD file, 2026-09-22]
hardware/enclosure/solar_panel_mount.stl
156.5 x 156.5 x 54.4

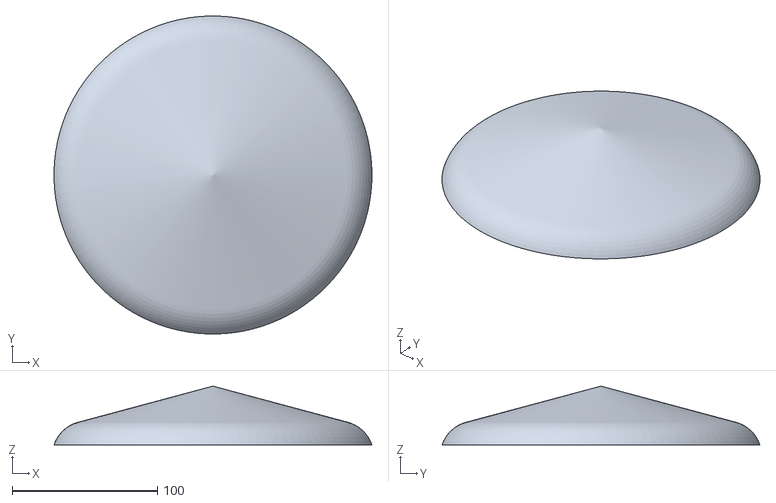
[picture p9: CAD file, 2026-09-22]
hardware/enclosure/lid_cap.stl
218.6 x 218.6 x 40.4

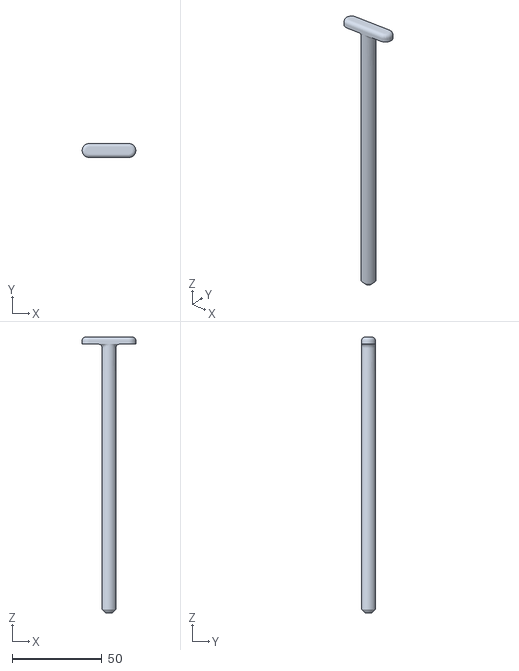
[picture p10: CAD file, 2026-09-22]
hardware/enclosure/vertical_rod.stl
30.0 x 7.80 x 154.0

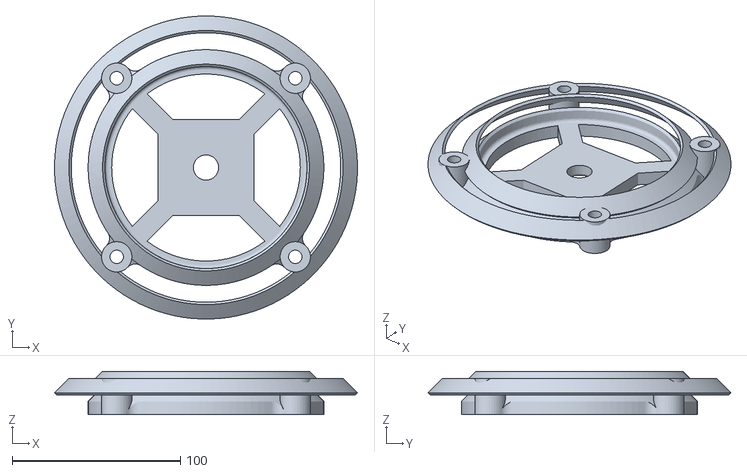
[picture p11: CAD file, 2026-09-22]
hardware/enclosure/base.stl
180.0 x 180.0 x 25.8

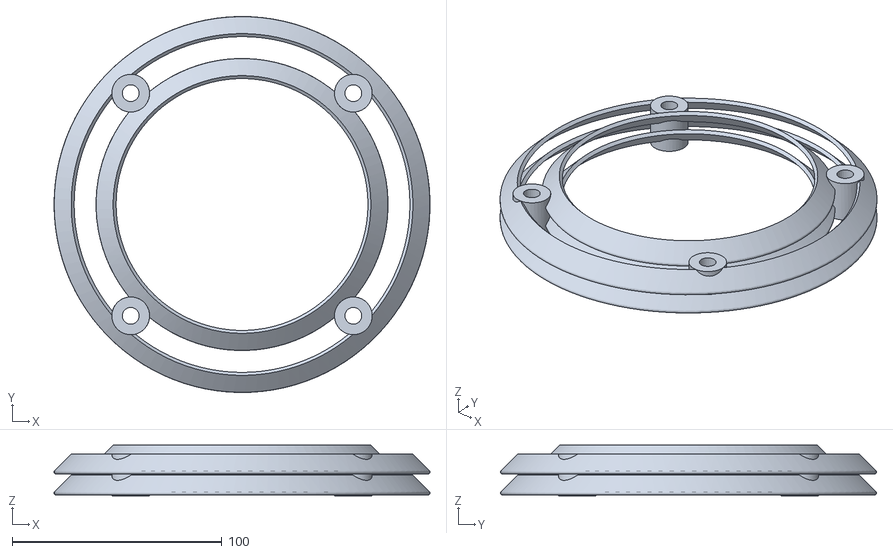
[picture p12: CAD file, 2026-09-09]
hardware/enclosure/screen.stl
179.1 x 179.2 x 24.2

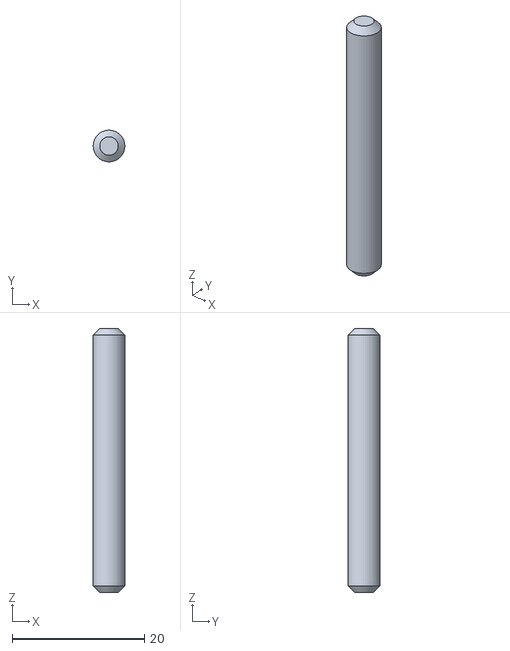
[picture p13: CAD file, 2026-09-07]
hardware/enclosure/horizontal_rod.stl
4.79 x 4.80 x 40.0

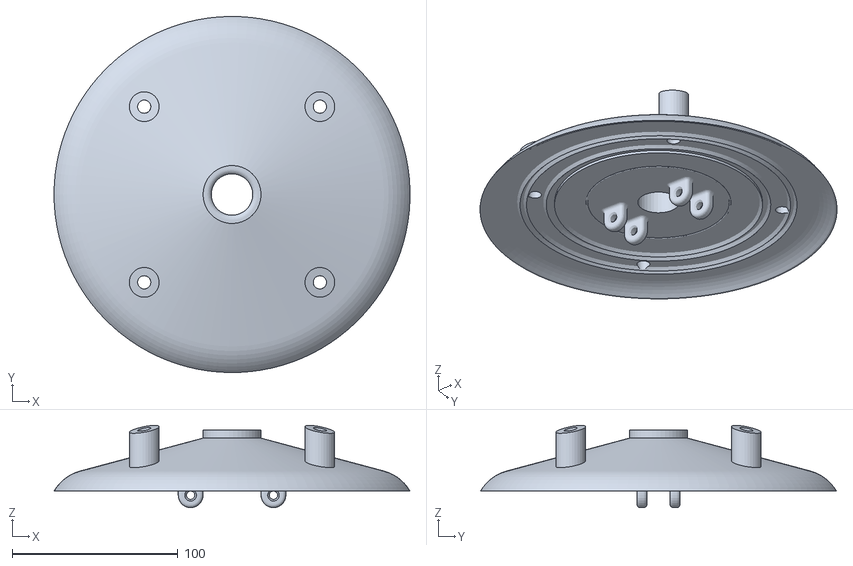
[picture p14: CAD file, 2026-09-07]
hardware/enclosure/lid.stl
215.0 x 215.0 x 49.7

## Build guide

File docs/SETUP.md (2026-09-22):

# Setup: Firmware Flashing & Gateway Stack

Step-by-step instructions for getting a CrimsonKestrel node flashed and its gateway stack running.
For hardware assembly and wiring, see [BRINGUP.md](../BRINGUP.md). For sensor/schema/LED reference
material, see [REFERENCE.md](REFERENCE.md).

---

#### 🔧 Arduino IDE & Hardware Configurations
To flash this firmware cleanly and unlock full hardware capabilities:
1. **Board Package:** Install **ESP32 Core by Espressif Systems (v3.0.0+)** via the Boards Manager.
2. **Flash Size:** Select **16MB (128Mb)** under *Tools > Flash Size*.
3. **Partition Scheme (CRITICAL):** Change this from the default "RainMaker 4MB" to **16M Flash (3MB APP/9.9MB FATFS)**.
   * *Why:* This leaves 3MB of space for heavy application binaries (allowing room for future sensor libraries) and carves out **9.9 Megabytes of local File System space (FATFS)** for offline caching.
4. **USB CDC On Boot:** Set to **Enabled** to allow direct `Serial.print()` routing over the built-in USB/JTAG controller without an external programmer.
5. **Erase All Flash Before Sketch Upload:** Set to **Disabled** to prevent erasing your local Wi-Fi profiles or FATFS files across programming cycles.

---

#### ⚙️ Gateway & Data Ingestion Pipeline
To show a complete end-to-end proof of concept, this repository includes a dedicated Python daemon to run on your indoor gateway server. The **crimson_kestrel_daemon.py** acts as the database-ingestion tier. It subscribes to both weather and system topics, performs strict schema validation and safety checks in real-time, and handles rotative CSV logging natively.

To provide complete, Staff-level end-to-end system validation, **CrimsonKestrel** includes a decoupled ingestion and database tier that resides on your indoor gateway server (like a permanently powered Raspberry Pi):
1. **crimson_kestrel_daemon.py**: A robust, class-based Python background daemon that subscribes to all node topics via wildcards (`telemetry/+/weather` and `telemetry/+/system`), validates payloads against strict sanity ranges, logs data to daily rolling CSV files, and streams metrics directly to InfluxDB.
2. **docker-compose.yml**: A single-command orchestration stack that spins up **Mosquitto** (MQTT), **InfluxDB 2.7** (Time-Series Database), and **Grafana** (Visualization UI).
3. **grafana_dashboard.json**: A pre-configured, beautiful Grafana Dashboard template that you can import with a single click to instantly chart live temperature, humidity, battery charge levels, and system health metrics.

##### 🚀 1. Spin Up the Ingestion Stack
On your gateway server, from the repo root, copy `.env.example` to `.env` and fill in real credentials (InfluxDB admin user/password/org/bucket/token, Grafana admin user/password), then spin up the Docker containers:
```bash
cp .env.example .env
# edit .env with your own credentials
docker compose up -d
```
This will instantly initialize:
*   **Mosquitto MQTT Broker** listening on port 1883.
*   **InfluxDB 2.7** on port 8086 (organization/bucket as configured in `.env`).
*   **Grafana** on port 3000 (credentials as configured in `.env`).

##### 🐍 2. Run the Telemetry Daemon
Ensure the `influxdb-client` and `paho-mqtt` packages are installed on your gateway:
```bash
pip install paho-mqtt influxdb-client
```
Now execute the daemon, pointing it to your local Mosquitto broker and your newly spun-up InfluxDB instance, using the same values you set in `.env`:
```bash
python3 gateway/crimson_kestrel_daemon.py \
  --host localhost \
  --port 1883 \
  --outdir ./data \
  --influx-url http://localhost:8086 \
  --influx-token "<INFLUX_TOKEN from .env>" \
  --influx-org "<INFLUX_ORG from .env>" \
  --influx-bucket "<INFLUX_BUCKET from .env>"
```
The daemon will now intercept, validate, and write every incoming single-shot MQTT transmission to BOTH your daily local CSV log files and InfluxDB simultaneously!

##### 🎨 3. View Your Grafana Dashboard
The InfluxDB data source and the `gateway/grafana_dashboard.json` dashboard are both auto-provisioned on startup — no manual "Add data source" or "Import" steps needed. Grafana reads them from `grafana/provisioning/` (mounted into the container by `docker-compose.yml`), with the data source's organization/token/bucket pulled straight from your `.env` file.

1. Open your browser and navigate to `http://<GATEWAY_IP>:3000` (log in using the `GRAFANA_ADMIN_USER` / `GRAFANA_ADMIN_PASSWORD` you set in `.env`).
2. Go to **Dashboards** and open **CrimsonKestrel Weather Station Dashboard** — it's already there.

You will instantly be presented with a responsive, professional dashboard displaying your ambient environmental indices and live battery curves side-by-side!

##### 💾 Grafana Data Persistence

Grafana's own state (its SQLite database, alerting history, uploaded plugins) is bind-mounted to `./grafana/data` on the host rather than a Docker-managed named volume. This is a deliberate choice: keeping it inside the repo directory means the data is visible and easy to back up or inspect alongside everything else, instead of being tucked away under Docker's internal volume storage.

The trade-off is a permissions gotcha. The `grafana` service runs as `user: "472:472"` in `docker-compose.yml` (matching the `grafana` user baked into the official image), but `./grafana/data` is created and owned by whatever host user first ran `docker compose up`. If that host UID isn't 472, Grafana fails on startup with:
```
Error: ✗ failed to check table existence: unable to open database file: permission denied
GF_PATHS_DATA='/var/lib/grafana' is not writable.
```
Fix this by giving UID 472 real ownership of the directory:
```bash
sudo chown -R 472:472 grafana/data
```
This is the correct fix — it makes the on-disk owner match the user the container actually runs as, rather than loosening the directory's permission bits for every user on the host (e.g. `chmod -R o+rwX`), which "works" but leaves Grafana's session/db data world-writable for no reason beyond convenience.

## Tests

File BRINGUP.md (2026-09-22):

# CrimsonKestrel Phase 1 Prototype Bring-Up Guide

This guide details the step-by-step process for safely assembling, wiring, and performing the first-time hardware validation of the **CrimsonKestrel (v1.15.2)** environmental telemetry node.

<p align="center">
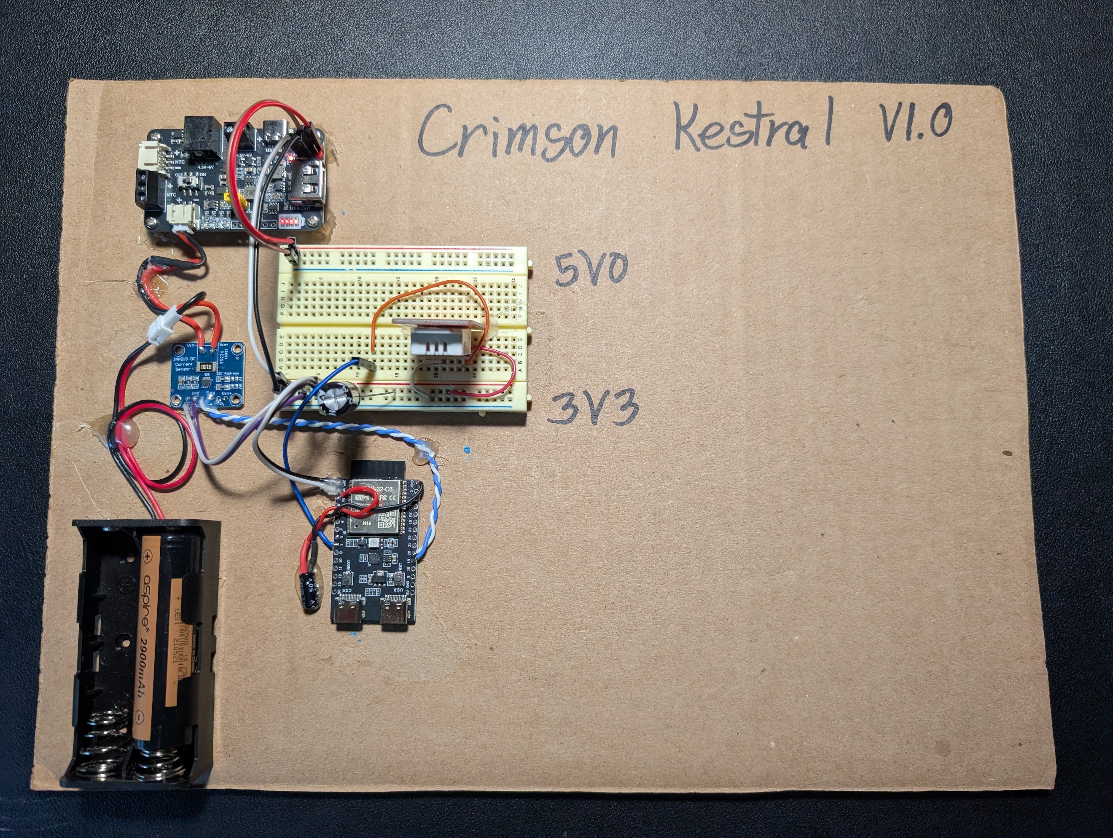
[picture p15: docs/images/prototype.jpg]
CrimsonKestrel Physical Cardboard-Mounted Bench Prototype
  
  <br>
  <em>The physical R&D cardboard-mounted bring-up bench setup</em>
</p>

Following the cardboard-mounted layout shown in your physical prototype, this guide is designed for zero-support repeatability, allowing other engineers to successfully execute the build without risk of damaging sensitive CMOS components.

---

## 🏗️ 1. Physical Bench Layout & Safety Configuration

The cardboard breadboard layout (The "Cardboard Test Bench") is a highly practical and safe prototyping strategy to prevent accidental short-circuits with stray metal tools or wires on your desk.

### Power & Ground Rails
Your board is physically separated into two distinct power zones driven by the **WatangTech Solar Charge Controller**:
1. **5.0V Rail (Top):** Powered by the WatangTech 5V USB/Terminal output. In Phase 1, this rail remains mostly inactive during deep sleep but is available to drive high-draw components or fans if expanded.
2. **3.3V Rail (Bottom):** Main system logic power rail. **All sensitive electronics (ESP32-C6, DHT22, and INA219) must run off this rail to prevent logic level mismatches or overvoltage damage**.

### Ground Plane Integrity (Star Grounding)
High-speed wireless transmissions (ESP32-C6 Wi-Fi 6 active bursts) can introduce severe high-frequency transient noise onto the power paths.
* **Rule:** Tie the ground pins of the ESP32-C6, the INA219 breakout, the DHT22 sensor, and the WatangTech battery output directly to a single shared rail on your breadboard (a **Star Ground Configuration**). This prevents ground loops and stabilizes analog sensor measurements.
* **Filter Capacitors:** Solder or insert a **$10\mu\text{F}$ to $100\mu\text{F}$ electrolytic capacitor** across the 3.3V power rail directly where it enters the breadboard to buffer transient current spikes, along with a **$0.1\mu\text{F}$ ceramic decoupling capacitor** close to the power pins of the ESP32-C6 and INA219.

---

## 🔌 2. Step-by-Step Wiring Connections

Refer to this absolute physical pin-to-pin wiring map when jumping components on your breadboard:

| Source Module Pin | Target ESP32-C6 Pin | Function | Wiring Notes |
| :--- | :--- | :--- | :--- |
| **DHT22 Pin 1 ($V_{CC}$)** | **3.3V Rail** | Sensor Power | Run directly from the common 3.3V breadboard rail. |
| **DHT22 Pin 2 (DATA)** | **GPIO1** | Single-Bus Serial | Connect directly to GPIO1 (chosen to avoid ESP32-C6 strapping-pin conflicts). |
| **DHT22 Pin 3 (NC)** | *Floating* | Not Connected | Leave disconnected. |
| **DHT22 Pin 4 (GND)** | **GND Rail** | System Ground | Connect directly to your star ground rail. |
| **INA219 VCC** | **3.3V Rail** | Chip Power | Powers the internal I2C ADC and logic gates. |
| **INA219 GND** | **GND Rail** | System Ground | Tie to your star ground rail. |
| **INA219 SDA** | **GPIO19** | I2C Data Line | Shared hardware I2C bus. |
| **INA219 SCL** | **GPIO20** | I2C Clock Line | Shared hardware I2C bus. |

### The Pull-Up Configuration Check
1. **DHT22 Data Line:** If you are using a bare 4-pin DHT22 sensor, you **must** place a physical $4.7\text{k}\Omega$ to $10\text{k}\Omega$ resistor between **Pin 1 ($V_{CC}$)** and **Pin 2 (DATA)**. If you are using a 3-pin pre-mounted breakout module, this resistor is already integrated on the module board.
2. **I2C Bus Pull-Ups:** Standard I2C requires strong physical pull-up resistors on the SCL and SDA lines to guarantee clean rise times. The internal software pull-ups on the ESP32-C6 are too weak (~$45\text{k}\Omega$) and will eventually cause communication hangs.
   * **The Hack:** Your INA219 breakout board features pre-soldered on-board $10\text{k}\Omega$ pull-up resistors. By simply wiring the INA219 directly to GPIO19 and GPIO20, the entire physical I2C bus is pulled up automatically without adding discrete resistors to your breadboard!

---

## ⚡ 3. Battery Power Path & Current Sensing (High-Side)

To accurately measure both active wireless peaks and ultra-low-power deep sleep sleep baselines, you must configure the INA219 in a **High-Side Sensing** topology:

```
[Battery V+] ──► [INA219 VIN+] ──► [0.1Ω Shunt Resistor] ──► [INA219 VIN-] ──► [To WatangTech Charger Input / Load]
```

1. Connect the **positive terminal** of your 18650 battery holder directly to the **$V_{IN+}$ terminal** of the INA219 module.
2. Connect the **$V_{IN-}$ terminal** of the INA219 module to the battery input on the **WatangTech Solar Charger Board**.
3. This configuration routes all system current directly through the on-board high-precision $0.1\Omega$ shunt resistor, allowing you to monitor active currents up to 3.2A and capture microamp sleep intervals seamlessly.
4. **Safety Check:** Ensure that the negative terminal (GND) of your battery holder is tied directly to the common ground rail of your breadboard.

---

## 💻 4. First-Time Flashing & Partition Table Setup

To write the partition map to the chip's physical registers, you must perform a specific sequence on your first USB flash:

### Arduino IDE Configurations (USB Connection)
Open the **Tools** menu in your Arduino IDE and match these parameters exactly:
* **Board:** "ESP32C6 Dev Module"
* **Flash Size:** "16MB (128Mb)"
* **Partition Scheme:** **`16M Flash (3MB APP/9.9MB FATFS)`**
* **USB CDC On Boot:** "Enabled"

### The First-Flash Sequence
1. Set **Erase All Flash Before Sketch Upload** to **`Enabled`**.
2. Plug your ESP32-C6 Core Board directly into your computer using a high-quality Type-C USB cable.
3. Select your active COM/TTY port under *Tools > Port*.
4. Click **Upload**. Enabling this setting is **required** on the first run to physically clear the factory register map and cleanly format the new 16MB partition boundaries.
5. **CRITICAL STEP:** Once the first upload completes successfully, immediately go back to *Tools > Erase All Flash Before Sketch Upload* and change it back to **`Disabled`**. 
   * *Why:* If left enabled, subsequent updates will completely wipe your local Wi-Fi profiles, non-volatile system registers (NVS), and cached local FATFS records on every upload!

---

## 🚦 5. Hardware Validation (Bring-Up Sequence)

### 🎨 WS2812 Visual Status LED Color Codes

To assist in local debugging and bring-up without having a serial monitor attached, the onboard WS2812 LED flashes standard, high-density color-coded states. Because these color codes are documented directly using GitHub-compatible hex swatches, they will render as beautifully colored visual dots directly on your GitHub landing page:

| LED State | Visual Swatch | Hex Code | R, G, B | System State & Meaning |
| :--- | :--- | :--- | :--- | :--- |
| **Solid Orange** | 🟧 ` #964B00 ` | `#964B00` | `150, 75, 0` | **System Booting:** Microcontroller powering up, establishing internal clock registers, and configuring hardware peripherals. |
| **Pulsing Yellow** | 🟨 ` #964B00 ` | `#964B00` | `150, 75, 0` (pulse) | **Wi-Fi Negotiating:** Active, non-blocking connection attempt to your local Wi-Fi gateway router. |
| **Flash Green** | 🟩 ` #009600 ` | `#009600` | `0, 150, 0` | **Publish Successful:** Environmental and system power telemetry successfully packaged and published to your MQTT broker. |
| **Solid Purple** | 🟪 ` #640064 ` | `#640064` | `100, 0, 100` | **Maintenance Window:** Active 2-second idle window listening on command topics for OTA override packages. |
| **Pulsing Cyan** | ⬜ ` #009696 ` | `#009696` | Variable | **Debug Loop Active:** Dynamic MQTT debug mode triggered; deep sleep is overridden to a rapid 5-second sampling loop. |
| **Solid Blue** | 🟦 ` #000096 ` | `#000096` | `0, 0, 150` | **OTA Mode Engaged:** Maintenance Mode active; the web-server is open and awaiting wireless firmware binaries. |
| **Pulsing Blue** | 🟦 ` #000096 ` | `#000096` | `0, 0, pulse` | **Active OTA Download:** High-speed wireless download of new compiled `.bin` firmware packets. |
| **Solid Cyan** | ⬜ ` #009696 ` | `#009696` | `0, 150, 150` | **Flash Write:** Actively committing new firmware blocks to local partition slots. |
| **Solid Green** | 🟩 ` #00FF00 ` | `#00FF00` | `0, 255, 0` | **Flash Success:** Firmware update completely written and verified; system is rebooting into the new software layer. |
| **Solid Red** | 🟥 ` #960000 ` | `#960000` | `150, 0, 0` | **System Error:** Hardware initialization failure (DHT22 missing, INA219 offline), or data sanitization outlier rejected. |
| **Fast Red Flash** | 🟥 ` #960000 ` | `#960000` | `150, 0, 0` (fast) | **Network Timeout:** Wi-Fi connection timed out or MQTT broker unreachable. Pipeline gracefully aborted to protect battery. |

Once flashed and powered up, monitor the onboard **WS2812 status LED** to verify that your hardware is initialized and communicating correctly:

```
[POWER ON] ──► SOLID ORANGE (Booting Peripherals)
                  │
                  ├──► Success? ──► PULSING YELLOW (Negotiating Wi-Fi)
                  │                    │
                  │                    ├──► Connected? ──► SOLID PURPLE (2s Listening Window)
                  │                    │                      │
                  │                    │                      └──► FLASH GREEN (Data Sent Ok!)
                  │                    │
                  │                    └──► Timeout? ──► FLASH RED & GO TO SLEEP
                  │
                  └──► INA219 Missing? ──► SOLID RED (Abort Pipeline)
```

### Expected Debug Console Log
Open your Serial Monitor set to **115200 Baud**. On power-up, you should see a clean, descriptive execution sequence:

```text
Firmware Version: 1.15.2 (Nested System, Power Stats & Secrets Include)
[SYSTEM] DHT22 initialized. Waiting 2s for sensor stabilization...
[SYSTEM] INA219 current monitor initialized successfully.
[SENSOR] DHT22 Temp: 22.4 C | Humidity: 41.2 %
[POWER] Bus Voltage: 3.95 V | Load Current: 42.1 mA
[POWER] INA219 placed in I2C Power-Down Mode (<15uA).
[WIFI] Establishing connection to <YOUR_WIFI_SSID>
......
[WIFI] Connected.
[WIFI] Node IP: <NODE_IP>
[MQTT] Subscribed to status and command topics.
[MQTT] Publishing weather package... success.
[MQTT] Publishing system package... success.
[MQTT] Nested CrimsonKestrel telemetry successfully published.
[SYSTEM] Listening for commands...
[SYSTEM] Entering deep sleep for 300 seconds.
```

If you encounter a **SOLID RED** LED on boot, immediately disconnect your power source, check for loose jumper wires on your SDA/SCL lines, and verify that the INA219 board is receiving stable 3.3V power.

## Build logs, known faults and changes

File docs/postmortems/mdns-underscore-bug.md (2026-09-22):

# Post-Mortem: The mDNS Underscore Bug

During initial integration testing of the wireless update (OTA) path on the **ESP32-C6**, the edge node successfully received MQTT command triggers, printed the callback receipt, and immediately crashed/went offline (`status offline`) in a permanent bootloop.

#### 🔍 Root Cause Analysis
This failure was traced back to a strict compliance check inside the modern **ESP-IDF v5.1+ / Arduino ESP32 Core v3.0+** network stack:
1. **RFC 1035 Hostname Spec Violation:** Under RFC 1035 (the domain name specification), hostnames are strictly restricted to alphanumeric characters and hyphens ( - ). **Underscores ( _ ) are illegal** in network hostnames.
2. **The Underscore Crash:** The codebase configured the mDNS hostname using the main MQTT client ID: `ArduinoOTA.setHostname(MQTT_CLIENT_ID);`, which resolved to `"weather_node_01"`.
3. **Internal Assertion Panic:** Upon calling `ArduinoOTA.begin()`, the ESP32-C6 attempted to register the mDNS service. The strict underlying ESP-IDF stack encountered the illegal underscore, resulting in a silent assertion failure, memory panic, and an immediate hardware watchdog or register-level CPU reset.
4. **Retained Message Loop:** Because the OTA trigger command was sent to the MQTT broker with the **retained** flag, the broker automatically re-published the "ON" state to the board as soon as it booted back up and reconnected, trapping the firmware in an infinite crash-on-boot cycle.

#### 🛡️ Core Remedies Implemented in v1.15.4
*   **mDNS Sanitization:** The mDNS setup task has been updated to dynamically replace illegal underscores with RFC 1035-compliant hyphens:
    ```cpp
    String dnsName = String(MQTT_CLIENT_ID);
    dnsName.replace("_", "-");
    ArduinoOTA.setHostname(dnsName.c_str()); // Resolves to "weather-node-01" (RFC-compliant)
    ```
*   **Explicit Port & Password Declarations:** Restored missing explicit initializers for `ArduinoOTA.setPort(OTA_PORT)` and `ArduinoOTA.setPassword(OTA_PASSWORD)` to secure the wireless flash pipeline.
*   **Safety Operational Guidelines:** Wiped retained state flags on the Mosquitto broker by publishing null payloads with the `-r` flag to clear the bootloop.

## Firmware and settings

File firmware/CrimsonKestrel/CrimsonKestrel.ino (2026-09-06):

/**
 * @file CrimsonKestrel_v1_15_2.ino
 * @brief Professional Solar Telemetry Node with WDT, OTA Rollback, MQTT LWT, and Retained MQTT Debug Sleep Override
 * @target ESP32-C6 (RISC-V, N16 16MB Flash)
 * @author Marshall Wingerson (Senior Embedded Systems Engineer)
 * 
 * Production-Grade Architecture (Phase 1 MVP - Decoupled Metrics & Versioning):
 * 1. Hardware Watchdog Timer (WDT) enabled with a 15-second timeout to recover from Wi-Fi or I2C hangs.
 * 2. OTA Rollback Guard active. If a wireless firmware update fails to boot or connect, the system
 *    will automatically roll back to the last known stable firmware partition.
 * 3. MQTT Last Will & Testament (LWT) configured on the status topic to guarantee offline visibility.
 * 4. Non-blocking network connectivity with a strict connection timeout to prevent battery drain.
 * 5. WS2812 Addressable RGB NeoPixel status reporting for bench and field diagnostics.
 * 6. Structured JSON telemetry payload transmitting temperature, humidity, voltage, and current.
 * 7. Retained MQTT Debug Override:
 *    - Realizes the exact "Single-Shot Boot Pattern" used at runtime (reboots, reconnects, samples).
 *    - Uses an external state pattern via MQTT retained messages.
 *    - If the "cmd/weather_node_01/debug" topic is retained "ON", the deep sleep duration drops
 *      from 5 minutes to 5 seconds, allowing the developer to trace full connection sequences rapidly.
 */

#include <WiFi.h>
#include <Wire.h>
#include <Adafruit_Sensor.h>
#include <DHT.h>
#include <Adafruit_INA219.h>
#include <ArduinoJson.h>
#include <PubSubClient.h>
#include <ArduinoOTA.h>
#include <Adafruit_NeoPixel.h>
#include <esp_task_wdt.h>
#include <esp_ota_ops.h>

// ==========================================
// --- USER CONFIGURATION BLOCK -----------
// ==========================================
#if __has_include("secrets.h")
  #include "secrets.h"         // Pulls actual credentials locally [cite: 235]
#else
  #include "secrets.example.h" // Fallback template so repo compiles out-of-the-box [cite: 235]
#endif

#define MQTT_PORT           1883
#define MQTT_CLIENT_ID      "weather_node_01"

// MQTT Status & Telemetry Topics
#define FIRMWARE_VERSION    "1.15.3"
#define MQTT_TOPIC_WEATHER  "telemetry/weather_node_01/weather"
#define MQTT_TOPIC_SYSTEM   "telemetry/weather_node_01/system"
#define MQTT_TOPIC_STATUS   "telemetry/weather_node_01/status"
#define MQTT_CMD_OTA_TOPIC  "cmd/weather_node_01/ota"
#define MQTT_CMD_DEBUG_TOPIC "cmd/weather_node_01/debug" // Debug sleep override topic
#define MQTT_CMD_SLEEP_TOPIC "cmd/weather_node_01/sleep"
#define MQTT_TOPIC_LOG      "telemetry/weather_node_01/log"

// Operational Durations and Timeouts
#define SLEEP_DURATION_SEC  10       // Default deep sleep duration: 5 minutes (300 seconds)
#define OTA_LISTEN_MS       2000      // Time window to listen for incoming command packets (ms)
#define WDT_TIMEOUT_SEC     15        // Hardware Watchdog Timeout (seconds)
#define NET_TIMEOUT_MS      10000     // Network connection timeout (ms)
#define OTA_WATCHDOG_MS     300000    // 5-minute safety timeout inside active OTA loop

// Pin Configurations
#define DHTPIN              1         // GPIO1: Safe general-purpose pin (no strapping conflicts)
#define DHTTYPE             DHT22
#define ONBOARD_LED         8         // GPIO8: WS2812 addressable RGB LED on Meshnology Board
#define I2C_SDA             19        // GPIO19: SDA for INA219
#define I2C_SCL             20        // GPIO20: SCL for INA219

// ==========================================
// --- GLOBAL OBJECTS & STATE --------------
// ==========================================
DHT dht(DHTPIN, DHTTYPE);
Adafruit_INA219 ina219;
WiFiClient espClient;
PubSubClient mqttClient(espClient);
Adafruit_NeoPixel statusLED(1, ONBOARD_LED, NEO_GRB + NEO_KHZ800);

// Dynamic sleep tracking (resets to 300s default on boot, modified by retained MQTT callback)
uint32_t activeSleepDurationSec = SLEEP_DURATION_SEC; 

// State Flags
volatile bool otaModeActive = false;
volatile bool debugModeActive = false;
unsigned long otaWindowStartTime = 0;

// Struct to store telemetry package
struct TelemetryData {
  float temperature_c;
  float humidity_pct;
  float bus_voltage_v;
  float load_current_ma;
  float shunt_voltage_mv;
  bool sensors_valid;
};

// Forward Declarations
void setLEDColor(uint8_t r, uint8_t g, uint8_t b);
void enterDeepSleep(uint32_t seconds);
bool connectWiFi();
bool connectMQTT();
TelemetryData readSensors();
void mqttCallback(char* topic, byte* payload, unsigned int length);
void setupOTA();
void initWatchdog();
void feedWatchdog();
void logMsg(const String& msg);

// ==========================================
// --- MAIN INITIALIZATION & SETUP ----------
// ==========================================
void setup() {
  // 1. Boot Console & Status LED
  Serial.begin(115200);
  delay(250);
  Serial.println(F("\n========================================="));
  Serial.println(F("Waking up... Initializing CrimsonKestrel Edge Node"));
  Serial.println(F("Firmware Version: 1.15.4 (Robust Callback & Byte Diagnostics)"));
  Serial.println(F("========================================="));

  statusLED.begin();
  statusLED.setBrightness(40); // Set moderate brightness to protect battery
  setLEDColor(150, 75, 0);     // SOLID ORANGE: System booting/initializing

  // 2. Initialize Hardware Watchdog
  initWatchdog();

  // 3. Initialize Sensors
  dht.begin();
  Serial.println(F("[SYSTEM] DHT22 initialized. Waiting 2s for sensor stabilization..."));
  delay(2000); // Required cold-boot stabilization delay for DHT22 to avoid NaN
  feedWatchdog();

  Wire.begin(I2C_SDA, I2C_SCL);
  bool hasCurrentSensor = ina219.begin();
  if (!hasCurrentSensor) {
    Serial.println(F("[ERROR] INA219 current monitor not detected! Checking wiring."));
    setLEDColor(150, 0, 0);    // SOLID RED: Hardware failure state
    delay(1000);
  } else {
    Serial.println(F("[SYSTEM] INA219 current monitor initialized successfully."));
  }
  feedWatchdog();

  // 4. Sample Sensors (Single-shot execution)
  TelemetryData data = readSensors();
  feedWatchdog();

  // 5. Power Down INA219 to save power during sleep
  if (hasCurrentSensor) {
    Wire.beginTransmission(0x40);
    Wire.write(0x00);          // Configuration Register
    Wire.write(0x00);          // MSB (Power Down mode)
    Wire.write(0x00);          // LSB (Power Down mode)
    Wire.endTransmission();
    Serial.println(F("[POWER] INA219 placed in I2C Power-Down Mode (<15uA)."));
  }
  feedWatchdog();

  // 6. Connect & Transmit over Wi-Fi
  if (data.sensors_valid) {
    if (connectWiFi()) {
      feedWatchdog();
      mqttClient.setServer(MQTT_BROKER, MQTT_PORT);
      mqttClient.setCallback(mqttCallback);

      if (connectMQTT()) {
        feedWatchdog();
        // 1. Serialize and publish Weather telemetry
        StaticJsonDocument<192> weatherDoc;
        weatherDoc["client_id"] = MQTT_CLIENT_ID;

        JsonObject env = weatherDoc.createNestedObject("environment");
        env["temperature_c"] = round(data.temperature_c * 10.0) / 10.0;
        env["humidity_pct"] = round(data.humidity_pct * 10.0) / 10.0;

        char weather_buffer[192];
        serializeJson(weatherDoc, weather_buffer);
        logMsg("[MQTT] Publishing weather package: " + String(weather_buffer));

        bool weather_pub_ok = mqttClient.publish(MQTT_TOPIC_WEATHER, weather_buffer);
        feedWatchdog();

        // 2. Serialize and publish System/Power telemetry
        StaticJsonDocument<256> systemDoc;
        systemDoc["client_id"] = MQTT_CLIENT_ID;

        JsonObject sysObj = systemDoc.createNestedObject("system");
        sysObj["version"] = FIRMWARE_VERSION;
        sysObj["uptime_ms"] = millis();

        JsonObject power = systemDoc.createNestedObject("power");
        power["bus_voltage_v"] = round(data.bus_voltage_v * 100.0) / 100.0;
        power["load_current_ma"] = round(data.load_current_ma * 10.0) / 10.0;
        power["shunt_voltage_mv"] = round(data.shunt_voltage_mv * 100.0) / 100.0;

        char system_buffer[256];
        serializeJson(systemDoc, system_buffer);
        logMsg("[MQTT] Publishing system package: " + String(system_buffer));

        bool system_pub_ok = mqttClient.publish(MQTT_TOPIC_SYSTEM, system_buffer);
        feedWatchdog();

        // Visual feedback based on overall success
        if (weather_pub_ok && system_pub_ok) {
          logMsg("[MQTT] Nested CrimsonKestrel telemetry successfully published.");
          setLEDColor(0, 150, 0); // FLASH GREEN: Direct transmit success
          delay(500);
        } else {
          logMsg("[ERROR] One or more MQTT publishes failed.");
          setLEDColor(150, 0, 0); // SOLID RED: MQTT error
          delay(1000);
        }
        feedWatchdog();

        // 7. Active Listening Window for Command Packets
        Serial.printf("[SYSTEM] Listening for commands on '%s' and '%s' for %d ms...\n", 
                      MQTT_CMD_OTA_TOPIC, MQTT_CMD_DEBUG_TOPIC, OTA_LISTEN_MS);
        
        unsigned long listenStart = millis();
        while (millis() - listenStart < OTA_LISTEN_MS) {
          mqttClient.loop();
          delay(10);
          feedWatchdog();
          
          // Visual feedback depending on state
          if (otaModeActive) {
            break;
          } else if (debugModeActive) {
            // Pulse soft white/cyan in active debug mode
            uint8_t dPulse = (millis() % 500 < 250) ? 100 : 20;
            setLEDColor(dPulse, dPulse, dPulse);
          } else {
            setLEDColor(100, 0, 100); // SOLID PURPLE/MAGENTA: Idle listening window
          }
        }
      }
    }
  } else {
    Serial.println(F("[ERROR] Telemetry invalid. Aborting network pipeline to protect battery."));
    setLEDColor(150, 0, 0);       // SOLID RED: Validation failed
    delay(2000);
  }

  // 8. State Verification: Enter active OTA Mode loop or Deep Sleep
  if (otaModeActive) {
    setupOTA();
    otaWindowStartTime = millis();
    Serial.println(F("[OTA] Maintenance Mode engaged. Waiting for wireless firmware upload..."));
    setLEDColor(0, 0, 150);       // SOLID BLUE: Ready for OTA stream
  } else {
    // If the sketch booted successfully, validated metrics, and didn't crash,
    // we mark it as "valid" to prevent the bootloader from triggering an OTA rollback on next reset.
    esp_ota_mark_app_valid_cancel_rollback();
    enterDeepSleep(activeSleepDurationSec);
  }
}

// ==========================================
// --- CORE LOOP (OTA EXCLUSIVE) -----------
// ==========================================
void loop() {
  if (otaModeActive) {
    ArduinoOTA.handle();
    mqttClient.loop(); // Call MQTT loop to listen for dynamic cancel commands ("OFF")
    feedWatchdog();

    // Breathe Blue R&D LED effect during active OTA waiting window
    uint32_t pulse = (sin(millis() / 300.0) * 75) + 75;
    setLEDColor(0, 0, pulse); 

    // Safety watchdog: Prevent indefinite battery drain if upload is aborted
    if (millis() - otaWindowStartTime > OTA_WATCHDOG_MS) {
      logMsg("[OTA] Maintenance window expired without upload. Sleeping...");
      otaModeActive = false;
    }
    delay(5);
  } else {
    // Exit ramp triggered! If otaModeActive was toggled false by MQTT or timeout
    logMsg("[SYSTEM] OTA loop exited. Entering deep sleep...");
    esp_ota_mark_app_valid_cancel_rollback();
    enterDeepSleep(activeSleepDurationSec);
  }
}

// ==========================================
// --- HARDWARE READINGS --------------------
// ==========================================
TelemetryData readSensors() {
  TelemetryData data;
  data.sensors_valid = true;

  // Read DHT22
  data.humidity_pct = dht.readHumidity();
  data.temperature_c = dht.readTemperature();

  // Read INA219
  data.bus_voltage_v = ina219.getBusVoltage_V();
  data.shunt_voltage_mv = ina219.getShuntVoltage_mV();
  data.load_current_ma = ina219.getCurrent_mA();

  // Verify readings against sanity ranges
  if (isnan(data.humidity_pct) || isnan(data.temperature_c) || data.humidity_pct < 0.0 || data.humidity_pct > 100.0) {
    Serial.println(F("[ERROR] DHT22 sensor readings are out-of-bounds or NaN!"));
    data.sensors_valid = false;
  } else {
    Serial.printf("[SENSOR] DHT22 Temp: %.1f C | Humidity: %.1f %%\n", data.temperature_c, data.humidity_pct);
  }

  // Validate Bus Voltage
  if (isnan(data.bus_voltage_v) || data.bus_voltage_v < 0.0 || data.bus_voltage_v > 26.0) {
    Serial.println(F("[ERROR] INA219 bus voltage readings are anomalous or NaN!"));
    data.sensors_valid = false;
  } else {
    Serial.printf("[POWER] Bus Voltage: %.2f V | Load Current: %.1f mA\n", data.bus_voltage_v, data.load_current_ma);
  }

  return data;
}

// ==========================================
// --- NETWORK PIPELINES --------------------
// ==========================================
bool connectWiFi() {
  Serial.print(F("[WIFI] Establishing connection to "));
  Serial.println(WIFI_SSID);

  WiFi.mode(WIFI_STA);
  WiFi.begin(WIFI_SSID, WIFI_PASSWORD);

  unsigned long startAttemptTime = millis();
  while (WiFi.status() != WL_CONNECTED && millis() - startAttemptTime < NET_TIMEOUT_MS) {
    // Pulse Yellow LED to show connection attempt
    uint8_t yellowPulse = (millis() % 1000 < 500) ? 150 : 20;
    setLEDColor(yellowPulse, yellowPulse / 2, 0); 
    delay(250);
    Serial.print(F("."));
    feedWatchdog();
  }

  if (WiFi.status() == WL_CONNECTED) {
    Serial.println(F("\n[WIFI] Connected."));
    Serial.print(F("[WIFI] Node IP: "));
    Serial.println(WiFi.localIP());
    return true;
  } else {
    Serial.println(F("\n[ERROR] Wi-Fi connection timed out!"));
    setLEDColor(150, 0, 0); // SOLID RED: Network Timeout
    delay(1000);
    return false;
  }
}

bool connectMQTT() {
  unsigned long startAttemptTime = millis();
  while (!mqttClient.connected() && millis() - startAttemptTime < NET_TIMEOUT_MS) {
    Serial.print(F("[MQTT] Contacting broker... "));
    
    // Connect with Last Will and Testament (LWT) configured
    // LWT Topic: tele/weather_node_01/status, Payload: "offline", QoS: 1, Retained: true
    if (mqttClient.connect(MQTT_CLIENT_ID, MQTT_TOPIC_STATUS, 1, true, "offline")) {
      Serial.println(F("Connected."));
      
      // Publish "online" status immediately upon successful connection
      mqttClient.publish(MQTT_TOPIC_STATUS, "online", true);
      
      // Subscribe to triggers
      mqttClient.subscribe(MQTT_CMD_OTA_TOPIC);
      mqttClient.subscribe(MQTT_CMD_DEBUG_TOPIC); // Subscribe to debug override topic
      mqttClient.subscribe(MQTT_CMD_SLEEP_TOPIC); // Subscribe to dynamic sleep interval topic
      return true;
    } else {
      Serial.print(F("failed, rc="));
      Serial.print(mqttClient.state());
      Serial.println(F(". Retrying in 1.5 seconds..."));
      
      setLEDColor(150, 0, 0); // Fast Red Flash to signal broker connection issues
      delay(300);
      setLEDColor(100, 0, 100);
      delay(1200);
      feedWatchdog();
    }
  }

  if (!mqttClient.connected()) {
    Serial.println(F("\n[ERROR] MQTT connection timed out!"));
    return false;
  }
  return true;
}

void mqttCallback(char* topic, byte* payload, unsigned int length) {
  // 1. Create a safe copy of the payload
  char message[length + 1];
  for (unsigned int i = 0; i < length; i++) {
    message[i] = (char)payload[i];
  }
  message[length] = '\0';

  // 2. Build a diagnostic string of the payload's raw bytes (decimal ASCII values)
  String diag = "[MQTT Callback] Raw payload bytes (len=" + String(length) + "): [";
  for (unsigned int i = 0; i < length; i++) {
    diag += String((int)payload[i]);
    if (i < length - 1) diag += ", ";
  }
  diag += "]";
  logMsg(diag);

  // 3. Log raw message arrival
  logMsg("[MQTT Callback] Message arrived [" + String(topic) + "]: \"" + String(message) + "\"");

  // 4. Robust trimming of leading and trailing whitespace/newlines/control characters
  char* start = message;
  while (*start && (*start == ' ' || *start == '\t' || *start == '\r' || *start == '\n')) {
    start++;
  }
  int cleanLen = strlen(start);
  char* end = start + cleanLen - 1;
  while (end >= start && (*end == ' ' || *end == '\t' || *end == '\r' || *end == '\n')) {
    *end = '\0';
    end--;
  }

  // 5. Convert to String and make Uppercase for robust comparison
  String cleanMsg = String(start);
  cleanMsg.toUpperCase();
  logMsg("[MQTT Callback] Cleaned, uppercase payload: \"" + cleanMsg + "\"");

  // 6. Topic Routing & State Changes
  if (strcmp(topic, MQTT_CMD_OTA_TOPIC) == 0) {
    if (cleanMsg == "ON" || cleanMsg == "TRUE" || cleanMsg == "1") {
      logMsg("[MQTT Callback] OTA bypass triggered! Suspend sleep.");
      otaModeActive = true;
    } else if (cleanMsg == "OFF" || cleanMsg == "FALSE" || cleanMsg == "0") {
      logMsg("[MQTT Callback] OTA mode deactivated! Resuming sleep path.");
      otaModeActive = false;
    }
  } 
  else if (strcmp(topic, MQTT_CMD_DEBUG_TOPIC) == 0) {
    if (cleanMsg == "ON" || cleanMsg == "TRUE" || cleanMsg == "1") {
      logMsg("[MQTT Callback] Retained Debug mode active. Sleeping for 5s instead of dynamic/default interval.");
      activeSleepDurationSec = 5; // Force next sleep state to 5 seconds
      debugModeActive = true;
    } else {
      logMsg("[MQTT Callback] Debug mode inactive. Restoring sleep interval.");
      activeSleepDurationSec = SLEEP_DURATION_SEC; // Fallback to default
      debugModeActive = false;
    }
  }
  else if (strcmp(topic, MQTT_CMD_SLEEP_TOPIC) == 0) {
    uint32_t parsedSleep = atoi(start);
    if (parsedSleep > 0 && parsedSleep <= 86400) { // Safety limit: 1 day max
      activeSleepDurationSec = parsedSleep;
      logMsg("[MQTT Callback] Dynamic sleep interval updated to " + String(activeSleepDurationSec) + " seconds.");
    } else {
      logMsg("[ERROR] Invalid sleep duration payload: " + String(start));
    }
  }
}

// ==========================================
// --- OVER-THE-AIR CONFIGURATION ----------
// ==========================================
void setupOTA() {
  // 1. RFC 1035 mDNS Hostname compliance (Convert illegal underscores to hyphens to prevent ESP-IDF crash)
  String dnsName = String(MQTT_CLIENT_ID);
  dnsName.replace("_", "-");
  ArduinoOTA.setHostname(dnsName.c_str());

  // 2. Configure OTA network port & security password from secrets.h
  ArduinoOTA.setPort(OTA_PORT);
  ArduinoOTA.setPassword(OTA_PASSWORD);

  ArduinoOTA.onStart([]() {
    Serial.println(F("[OTA] Broadcast started. Receiving flash payload..."));
    setLEDColor(0, 150, 150); // SOLID CYAN: Active flash write in progress
  });
  ArduinoOTA.onEnd([]() {
    Serial.println(F("\n[OTA] Flash transfer completed. Rebooting..."));
    setLEDColor(0, 255, 0);   // SOLID GREEN: Flash successful
    delay(1000);
  });
  ArduinoOTA.onProgress([](unsigned int progress, unsigned int total) {
    Serial.printf("[OTA] Transmitting: %u%%\r", (progress / (total / 100)));
  });
  ArduinoOTA.onError([](ota_error_t error) {
    Serial.printf("[OTA] Error[%u] encountered! ", error);
    setLEDColor(255, 0, 0);   // SOLID RED: Flash failed
    delay(2000);
  });

  ArduinoOTA.begin();
  Serial.println(F("[OTA] Wireless network server active."));
}

// ==========================================
// --- WATCHDOG CONTROLS ---------------------
// ==========================================
void initWatchdog() {
#if CONFIG_IDF_TARGET_ESP32C6
  // Native ESP32-C6 core configuration for Arduino v3.0+
  esp_task_wdt_config_t wdt_config = {
    .timeout_ms = WDT_TIMEOUT_SEC * 1000,
    .idle_core_mask = 1 << 0, // Monitor core 0 (single core processor)
    .trigger_panic = true     // Reset chip on failure
  };
  esp_task_wdt_init(&wdt_config);
#else
  // Fallback compatibility for older board packages
  esp_task_wdt_init(WDT_TIMEOUT_SEC, true);
#endif
  esp_task_wdt_add(NULL);     // Add current task (main thread) to watchdog loop
  Serial.println(F("[SYSTEM] Hardware Watchdog Timer initialized."));
}

void feedWatchdog() {
  esp_task_wdt_reset();
}

// ==========================================
// --- POWER MANAGEMENT & SYSTEM DEEP SLEEP -
// ==========================================
void enterDeepSleep(uint32_t seconds) {
  Serial.print(F("[SYSTEM] Powering down... Entering Deep Sleep for "));
  Serial.print(seconds);
  Serial.println(F(" seconds."));

  // Power off NeoPixel completely to save battery
  setLEDColor(0, 0, 0);
  statusLED.show();

  // Disconnect Wi-Fi nicely
  WiFi.disconnect(true);
  delay(10);

  // Configure timer wake-up and sleep
  esp_sleep_enable_timer_wakeup((uint64_t)seconds * 1000000ULL);
  esp_deep_sleep_start();
}

/**
 * @brief Utility to print messages to Serial and publish to MQTT log stream
 */
void logMsg(const String& msg) {
  Serial.println(msg);
  if (mqttClient.connected()) {
    mqttClient.publish(MQTT_TOPIC_LOG, msg.c_str());
  }
}

/**
 * @brief Utility to push color values to WS2812 status NeoPixel
 */
void setLEDColor(uint8_t r, uint8_t g, uint8_t b) {
  statusLED.setPixelColor(0, statusLED.Color(r, g, b));
  statusLED.show();
}

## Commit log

2026-09-07 Designed the first pass enclosure
    A little bit of exploration on how others implement enclosures lead me to the Stevenson Screen. It is an old invention that uses louvers to avoid wind + water to affect sensitive equipment while allowing for free air movement. It was later revamped into a dual louver system for better weather rejection.
    This is my first pass at the weather station with a Stevenson Screen design. I still need to figure out how to mount the solar panel but the sections are all modular so I can replace them easily.
    [base_v0.5.stl, hoizontal_rod_v0.5.stl, lid_cap_v0.5.stl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]
2026-09-09 A couple of dashboard updates
2026-09-09 Updating enclosure base and screen to include missing louver
    [base_v0.5.stl, base_v0.6.stl, screen_v0.5.stl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]
2026-09-09 Adding enclosure STLs and updated README
    [base_v0.6.stl, hoizontal_rod_v0.5.stl, lid_cap_v0.5.stl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]
2026-09-14 Opening up permissions on my device since I am on a private network to make it easier for others to reach the dashboard
2026-09-22 Split README into docs/SETUP.md, docs/REFERENCE.md, and docs/postmortems/; remove stale doc-debt header
    The README had grown to 263 lines mixing pitch/overview, setup steps,
    lookup-later reference material, and a one-off post-mortem. Split by
    job to match the existing BOM.md/BRINGUP.md/adr/ pattern: setup steps
    move to docs/SETUP.md, firmware safeguards/LED codes/credentials
    pattern/JSON schemas move to docs/REFERENCE.md, and the mDNS bootloop
    write-up moves to docs/postmortems/. README.md now stays pitch +
    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
2026-09-22 Fix cross-doc pin/container-name drift and scrub real credentials from docs
    Repo-wide alignment pass after the README split (Register #9):
    - BOM.md, BRINGUP.md, and docs/cheatsheet.md all documented the DHT22
    DATA line on GPIO15; firmware ground truth is GPIO1. Fixed all three,
    and flagged the resulting GPIO1 collision with BOM.md's proposed
    Phase-2 SPS30 fan-control pin.
    - docs/cheatsheet.md referenced the removed telegraf container and used
    bare service names instead of docker-compose.yml's actual
    container_names (crimson_mosquitto/crimson_influxdb/crimson_daemon) -
    those example commands would have failed as written.
    - Scrubbed real gateway/node IPs, a real username, a real W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
2026-09-22 Drop per-file version suffixes from enclosure STLs ahead of v1.0
    Individual parts were being version-numbered independently
    (base_v0.6, lid_v0.5, vertical_rod_v0.7, etc.), which made it
    impossible to tell what "the enclosure" was at any given point.
    Moving to git as the source of truth for revision history instead;
    the assembly as a whole will be tagged as v1.0 once tidied up.
    Also fixed a filename typo (hoizontal_rod -> horizontal_rod) and
    folded the superseded v0.5/v0.6 parts into their v0.7 replacements.
    lid.stl/lid_cap.stl and vertical_rod.stl/vertical_rod_test.stl are
    kept as distinct parts (test rods are intentionally loose-fitting for
    dev use).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
    [base.stl, base_v0.6.stl, electronics_plate.stl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]
